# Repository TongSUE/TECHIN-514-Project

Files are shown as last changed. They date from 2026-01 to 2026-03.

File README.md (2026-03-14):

# TECHIN-514-Project : The Reality Color Dropper

## 1. Project Overview

**What it does:**
This project brings the digital "eyedropper" tool into real life. It consists of a pen-shaped device that scans the color of physical objects and a desktop station that displays the color data and the confidence level of the match. It helps designers capture colors from the real world instantly.

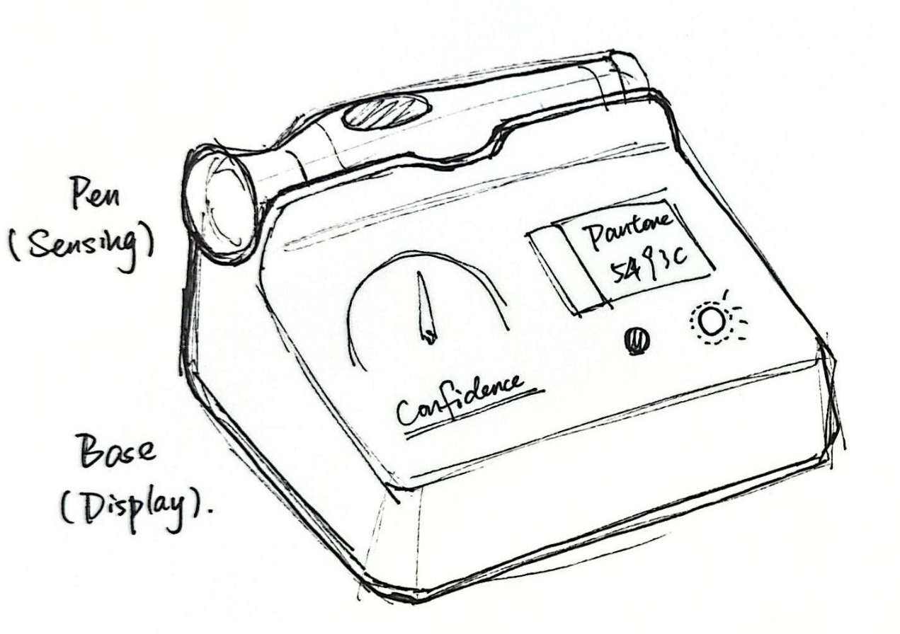
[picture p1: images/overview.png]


---

## 2. The Sensor Device (The Pen)

**Description:**
This is a handheld tool shaped like a marker pen. It utilizes a custom split-PCB architecture to fit the slim form factor. When the user finds a color, they press the button; the device reads the RGB value while blocking outside light and sends the data wirelessly to the base station.

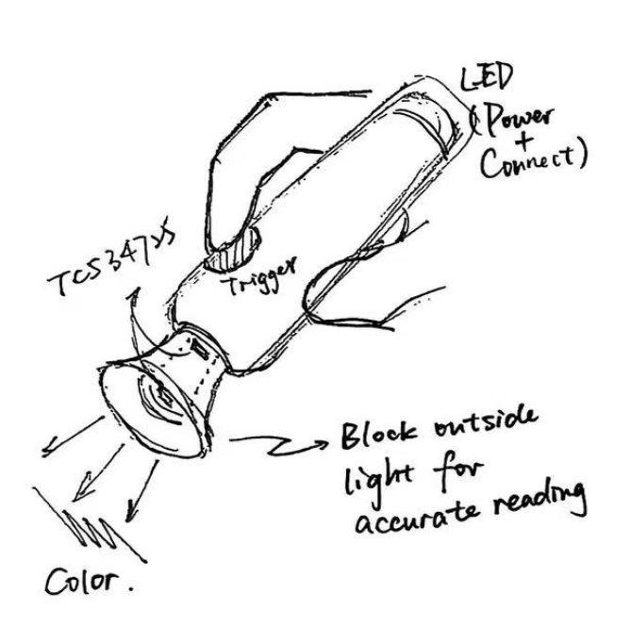
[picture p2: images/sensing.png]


**Key Components & Part Numbers:**

* **Controller: Seeed Studio XIAO ESP32C3**
    This thumb-sized microcontroller is selected for its compact footprint and built-in ESP-NOW capabilities. It fits perfectly inside the pen shaft.

* **Sensor Architecture: Split Custom PCB**
    To accommodate the pen's geometry, the circuit is split into two boards connected by a **1x4 Pin Header**:
    1.  **Main Board:** Vertically mounted inside the pen. Houses the MCU, battery pads, and switch.
    2.  **Sensor Tip:** A circular PCB mounted horizontally at the tip. Houses the **TCS34725 Sensor** and **LEDs** to ensure the sensor faces the paper perpendicularly.

* **Input: Tactile Button**
    Acts as a "shutter" trigger.

* **Power: Li-Po Battery (AAA size)**
    A cylindrical/prismatic lithium battery that connects to the motherboard via a battery holder.

* **Power Switch: Slide Switch**
    A side-mounted switch to cut off power completely.

---

## 3. The Display Device (The Base)

**Description:**
This is a desktop base that receives the color data. It features an OLED screen for data readout, a stepper motor gauge for visual feedback on accuracy, and a large LED for color reproduction.

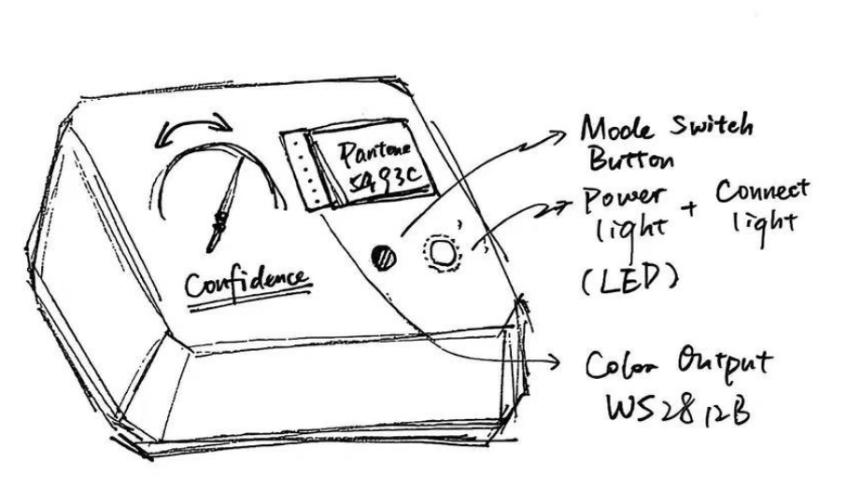
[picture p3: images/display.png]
Display device


**Key Components & Part Numbers:**

* **Controller: Seeed Studio XIAO ESP32C3**
    The base station uses the exact same controller as the pen. This unified architecture simplifies the codebase and BOM.

* **Display: 0.96" OLED Screen (SSD1306 Driver)**
    Displays the Hex/RGB codes via I2C interface.

* **Color Output: RGB LED**
    A programmable NeoPixel LED to visually visually recreate the scanned color.

* **Motor: x27_168 Stepper Motor**
    Indicates the "Confidence Level" (Euclidean distance) of the color match.

* **Power: 18650 Li-Ion Battery**
    Provides long-lasting power, boosted to 5V for the motor and LEDs.

---

## 4. System Logic & Communication

**Communication Method:**
The devices talk to each other using **ESP-NOW**.
* It is a peer-to-peer protocol (low latency).
* It does not require a router or Wi-Fi pairing.

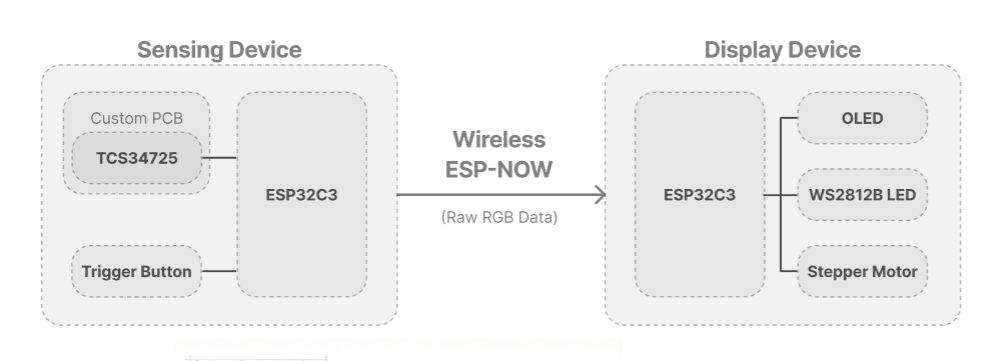
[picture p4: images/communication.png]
Communication


**Workflow:**

1.  **Trigger:** User clicks the pen button.
2.  **Sensing:** The TCS34725 sensor (on the Daughterboard) reads the Raw RGB data.
3.  **Sending:** The Pen (XIAO ESP32C3) processes the data and sends it via ESP-NOW.
4.  **Receiving:** The Base (XIAO ESP32C3) receives the packet.
5.  **Processing (DSP/ML):** The Base calculates the **Euclidean Distance** between the scanned color and a stored color library (KNN algorithm).
6.  **Output:**
    * The **OLED** shows the color code.
    * The **Neopixel LED** lights up in that color.
    * The **Stepper Motor** moves the needle to show the confidence level.

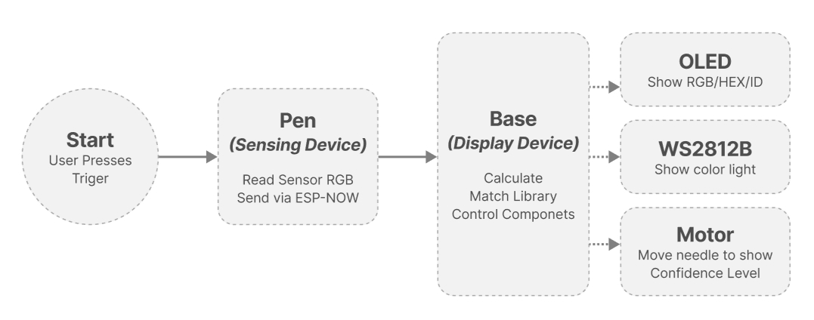
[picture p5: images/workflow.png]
Workflow


---

# Electrical Schematics & PCB Layout

## Custom PCB Design
The pen utilizes a custom **Split-PCB Design** to manage the directional requirements of the sensor.

The split-PCB architecture is implemented to allow the sensor to sit perpendicular to the scanning surface for accurate readings, while the main controller fits vertically within the narrow pen shaft.

* **Connection:** The Main Board and Sensor Tip are linked via a flexible **1x5 Connector** carrying 3.3V, GND, SDA, SCL, and LED Control.
* **Power:** The battery connects to the tail of the Main Board via a **1x2 Connector**.

### **Custom PCB Screenshots**
- Sensing - Sensor Tip
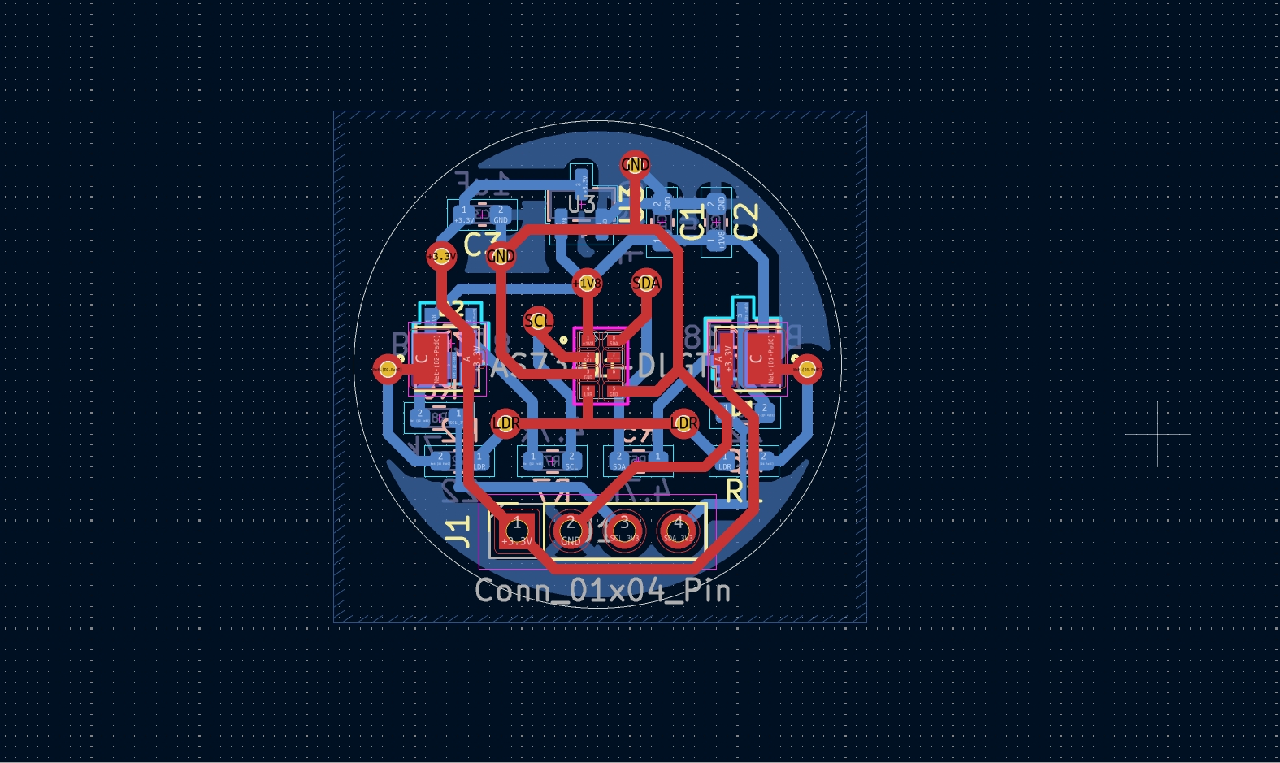
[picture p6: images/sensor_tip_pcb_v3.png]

- Sensing - Main Board
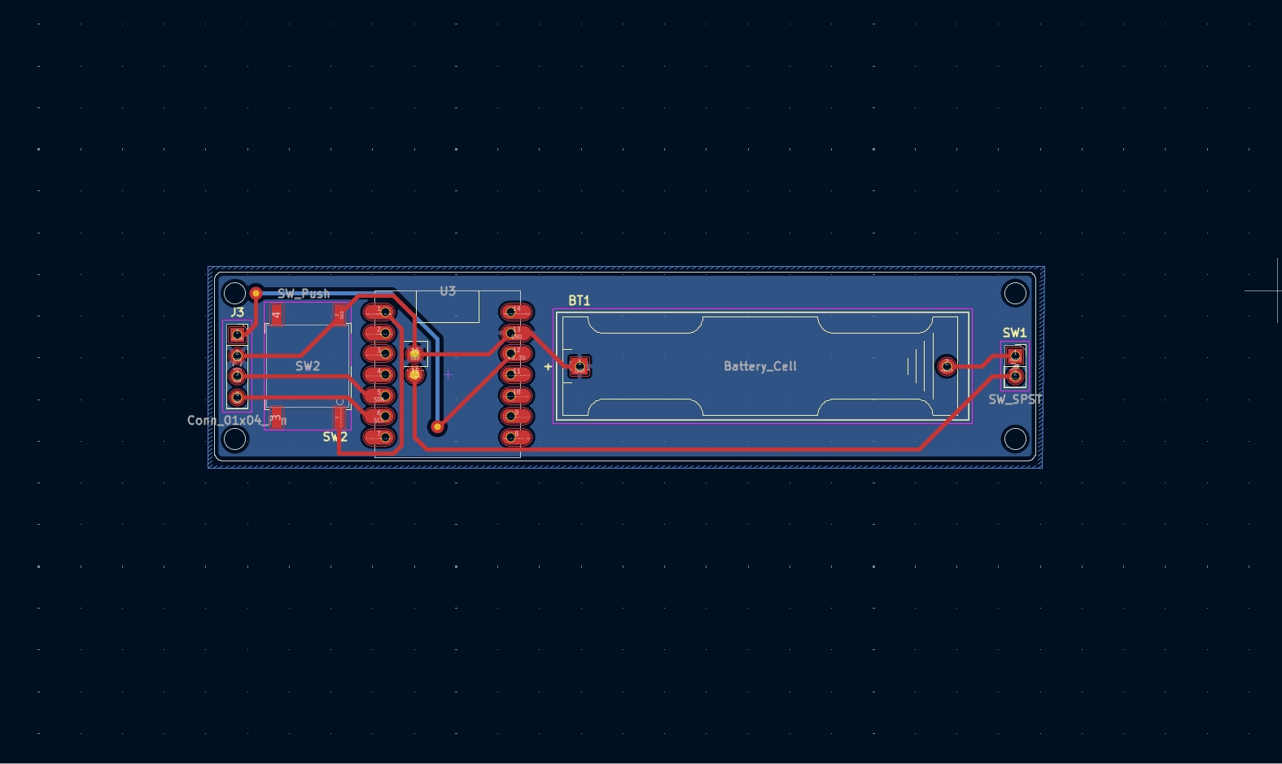
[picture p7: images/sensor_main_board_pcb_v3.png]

- Display
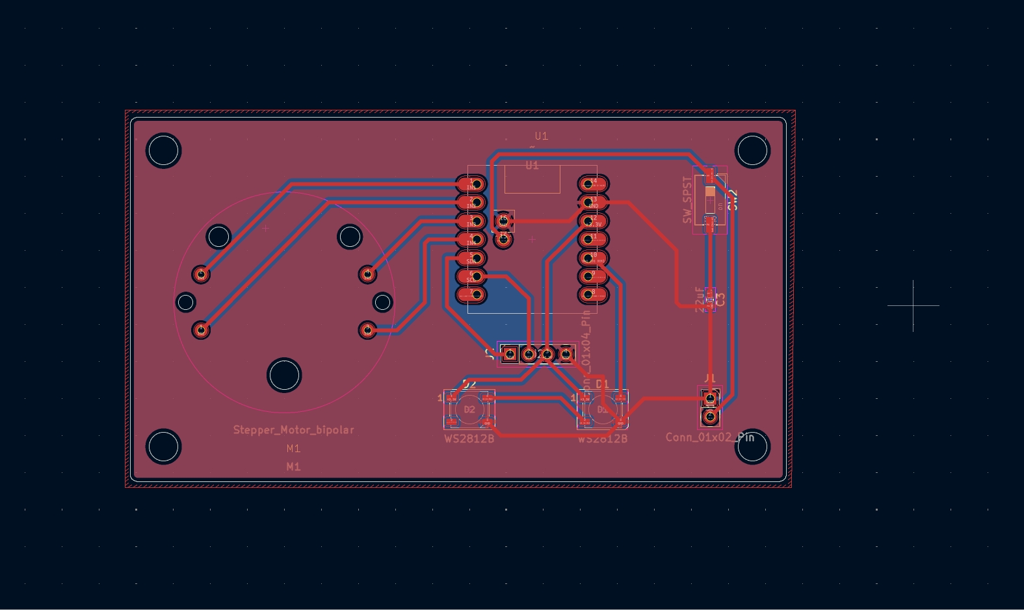
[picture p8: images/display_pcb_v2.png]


## Circuit Schematics

### **Sensing Device Schematic**
- Sensor Tip
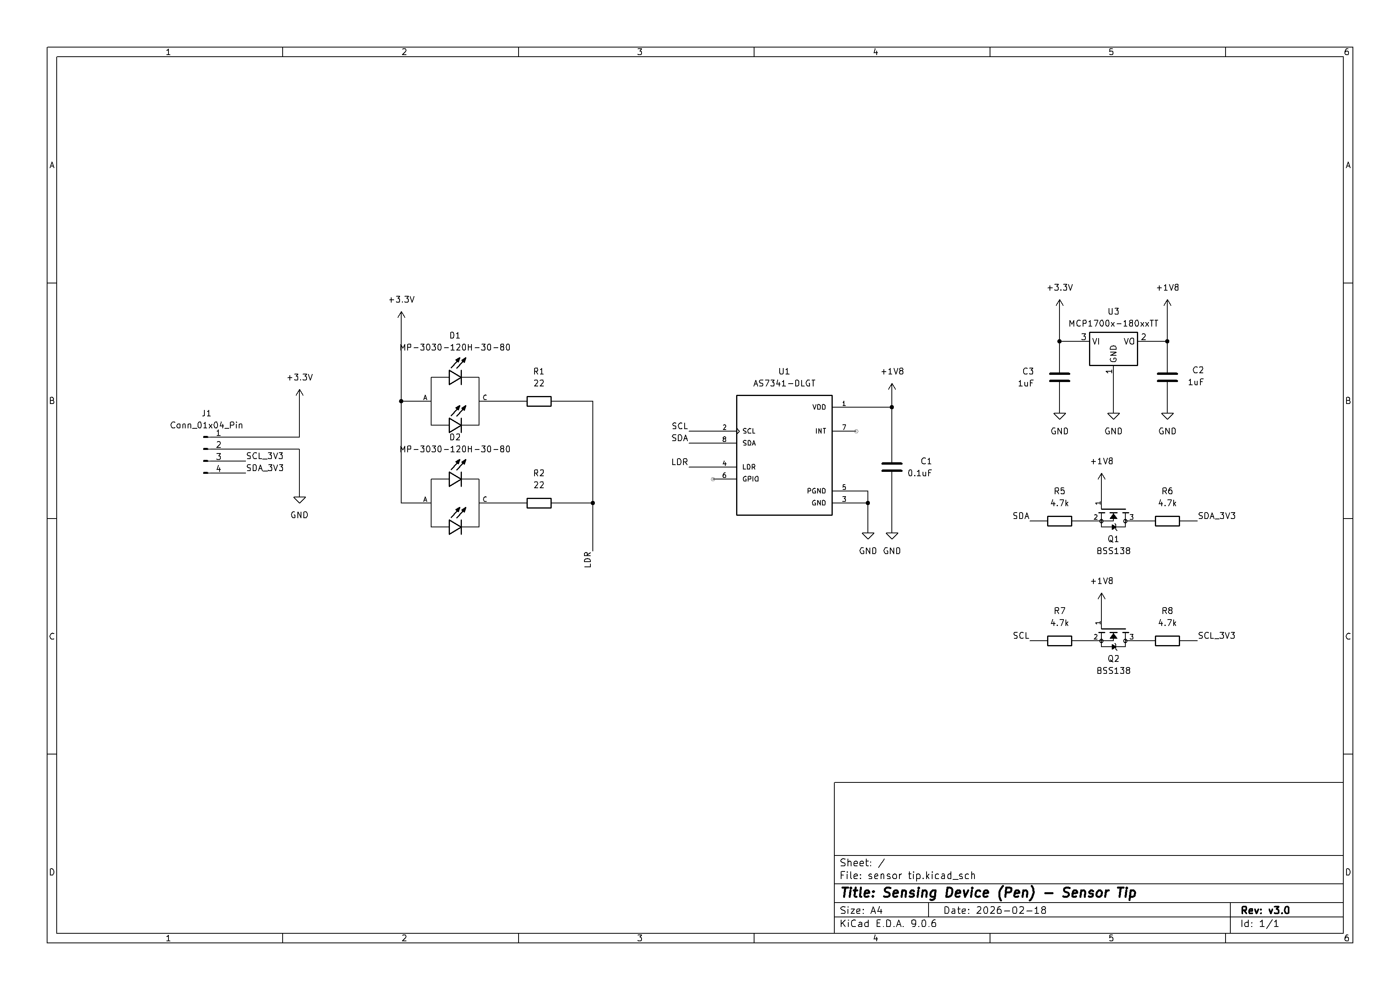
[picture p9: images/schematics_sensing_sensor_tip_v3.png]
Electrical schematics of Sensing device


- Main Board
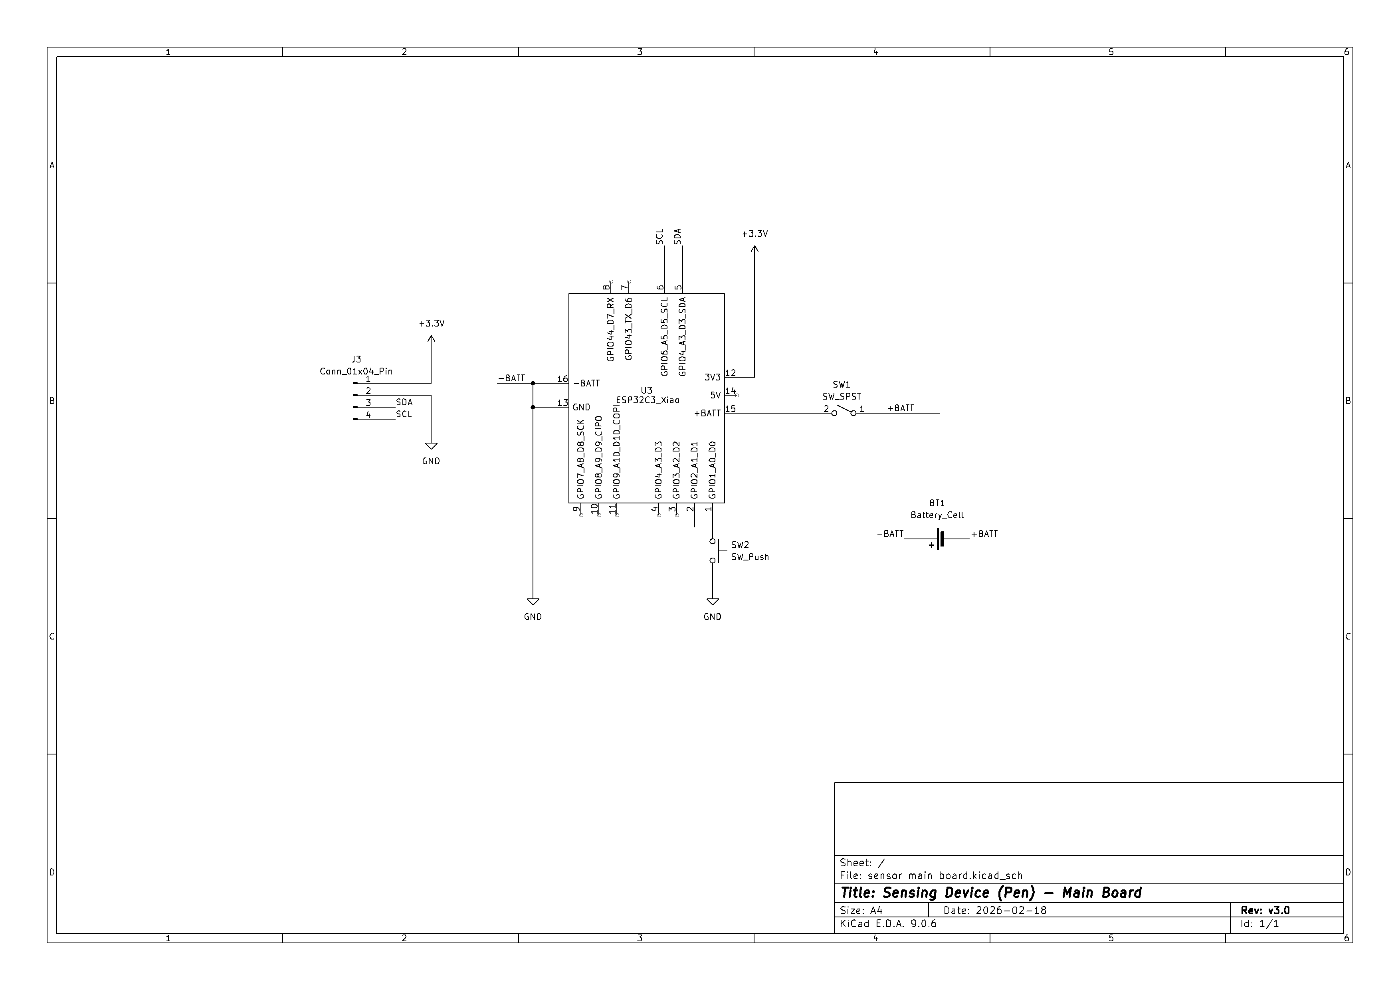
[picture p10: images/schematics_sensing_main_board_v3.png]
Electrical schematics of Sensing device


### **Display Device Schematic**

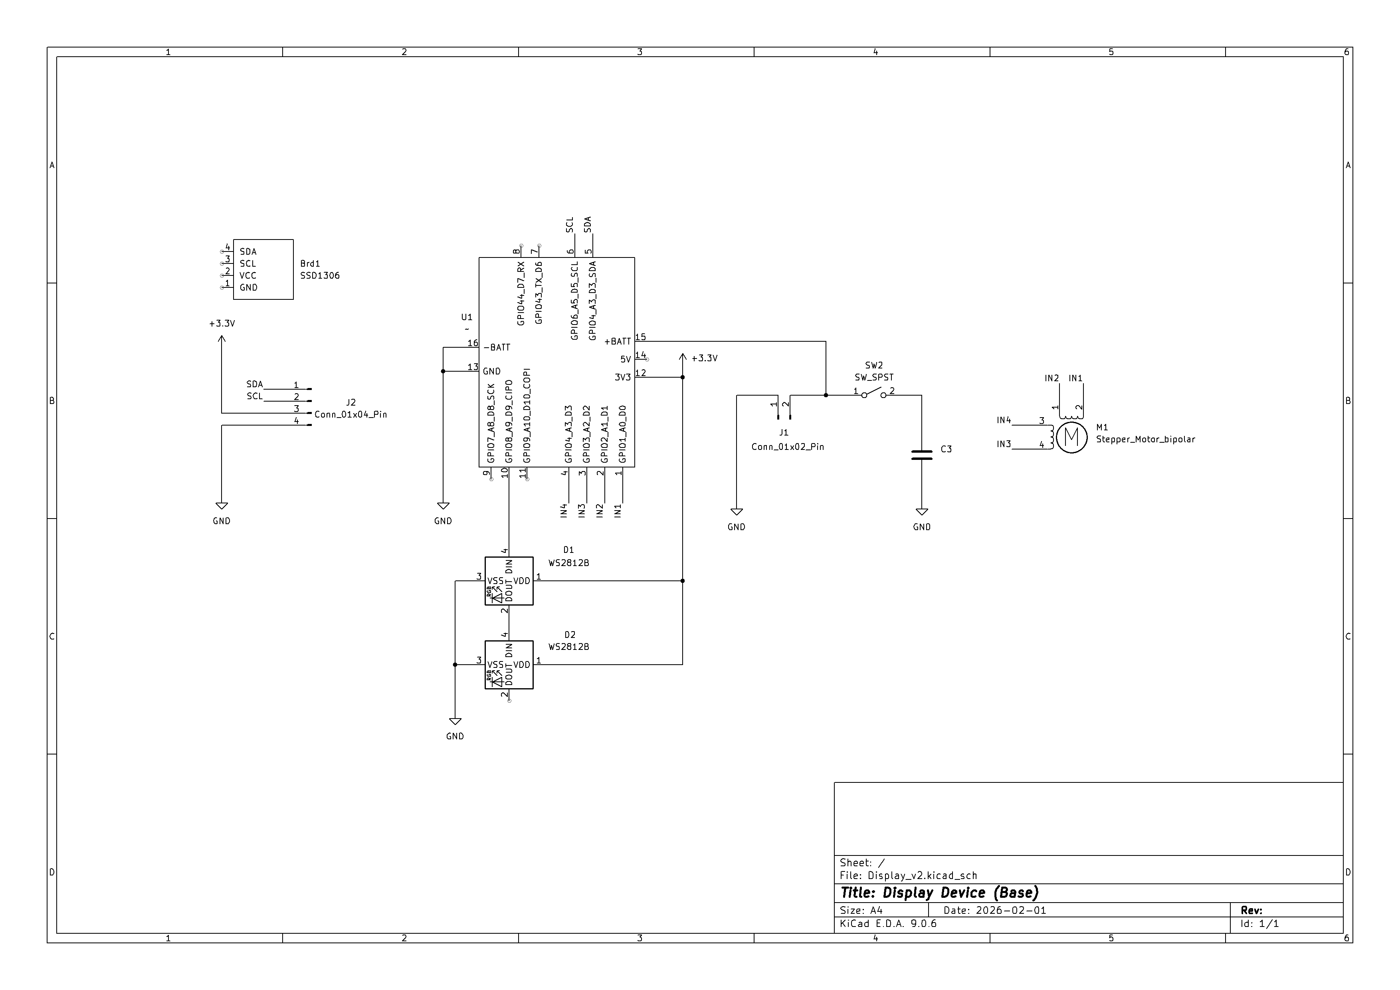
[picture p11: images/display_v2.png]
Electrical schematics of Display device


---

# BOM

- [Sensing - Sensor Tip BOM](./schematics/Sensing_v3/sensor%20tip/sensor%20tip.csv)
- [Sensing - Main Board BOM](./schematics/Sensing_v2/sensor%20main%20board.csv)
- [Display BOM](./schematics/Display_v2/Display_v2.csv)

---

# Battery Estimate
- [Simple Power Model (Google Doc)](https://docs.google.com/spreadsheets/d/19ngwSyrM9dyAIHHAB65ps8SqUUKRAjS5MIs19pbbb7s/edit?usp=sharing)

---

# Enclosure Design
- [Enclosure Design](./enclosure/)

### Sensing Device
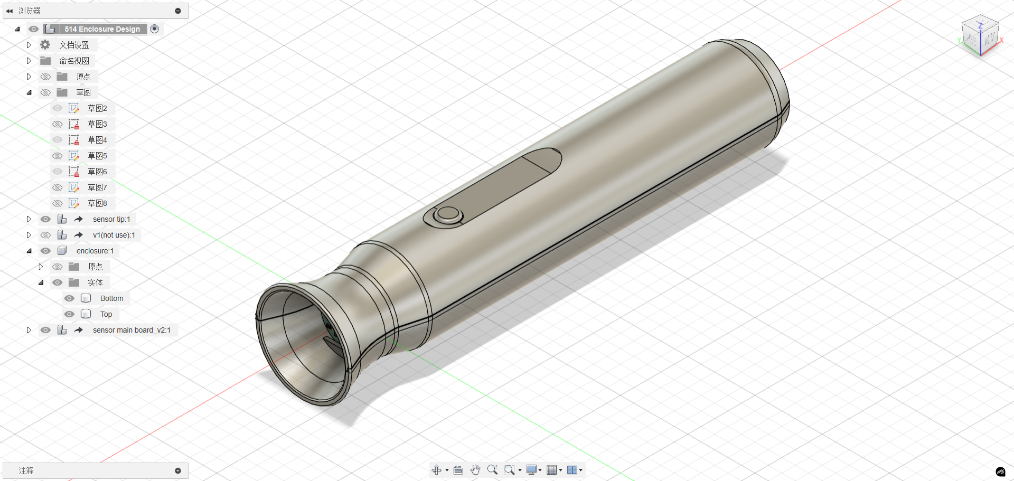
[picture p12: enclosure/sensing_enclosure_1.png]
Enclosure Design of Sensing device


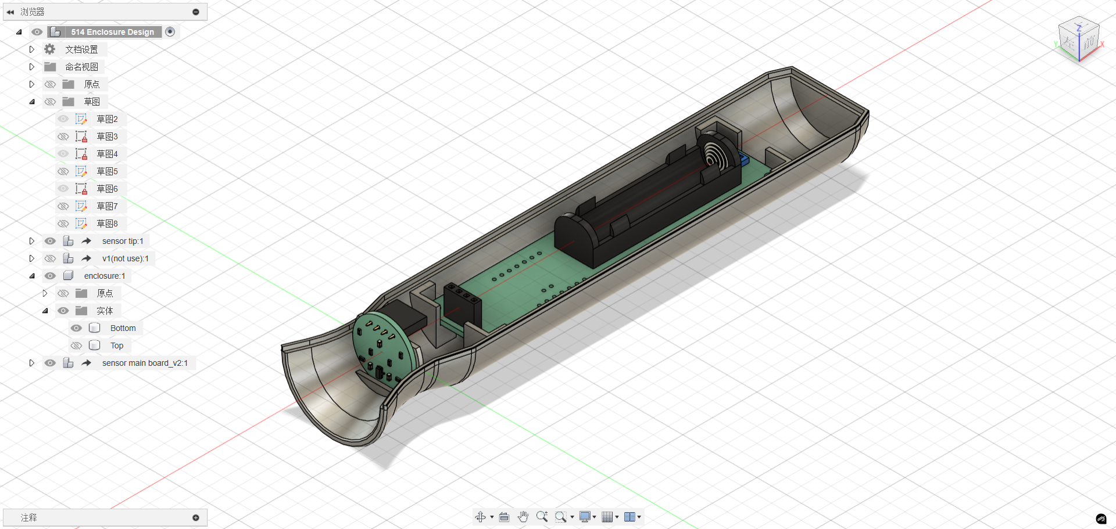
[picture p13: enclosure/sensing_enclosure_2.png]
Enclosure Design of Sensing device


### Display Device
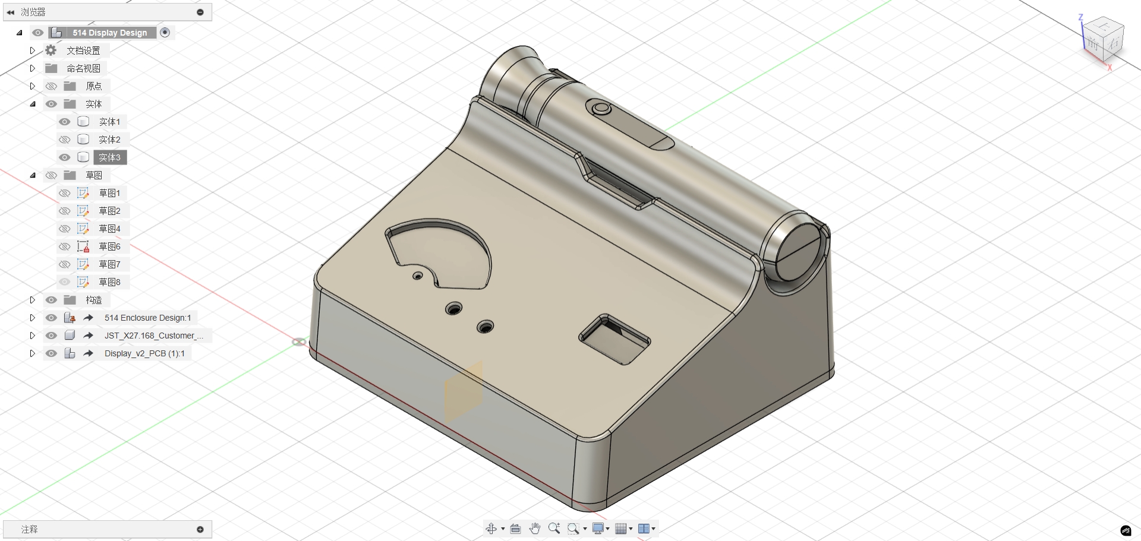
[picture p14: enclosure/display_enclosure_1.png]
Enclosure Design of Sensing device


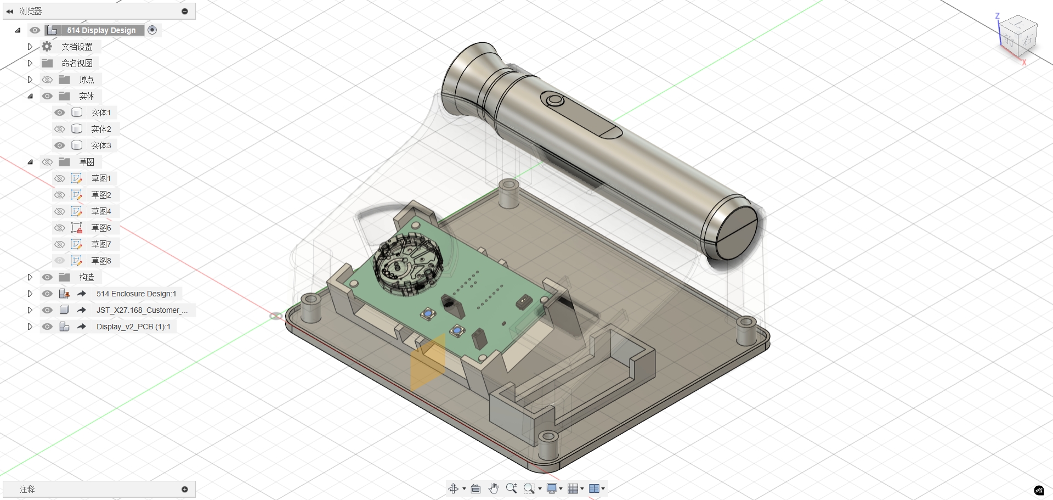
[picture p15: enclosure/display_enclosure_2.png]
Enclosure Design of Sensing device


---

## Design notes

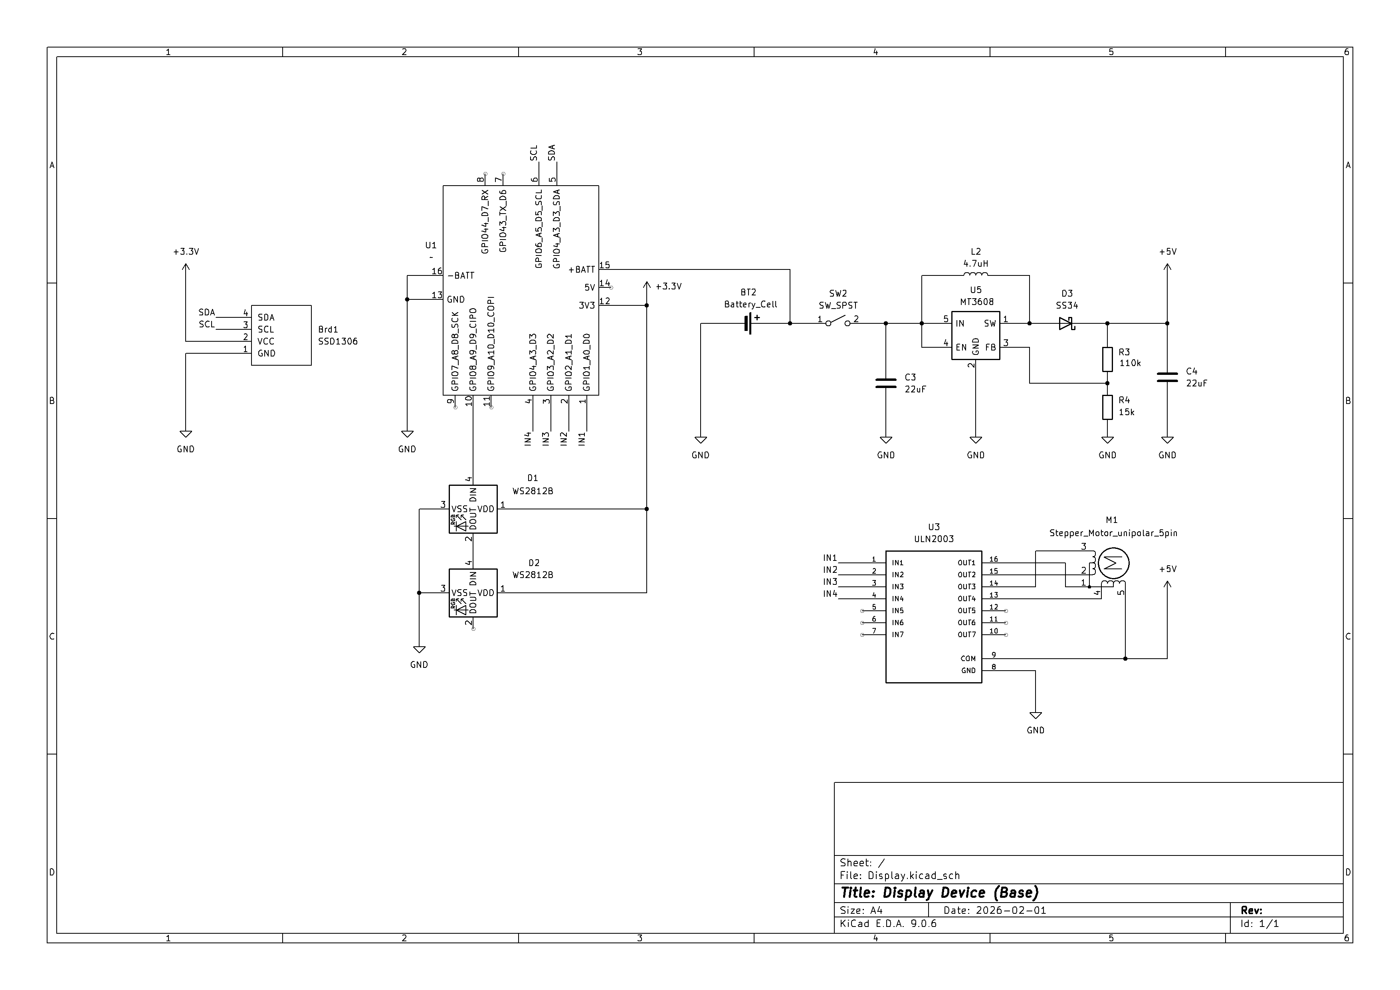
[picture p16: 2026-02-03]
images/schematics_display.png

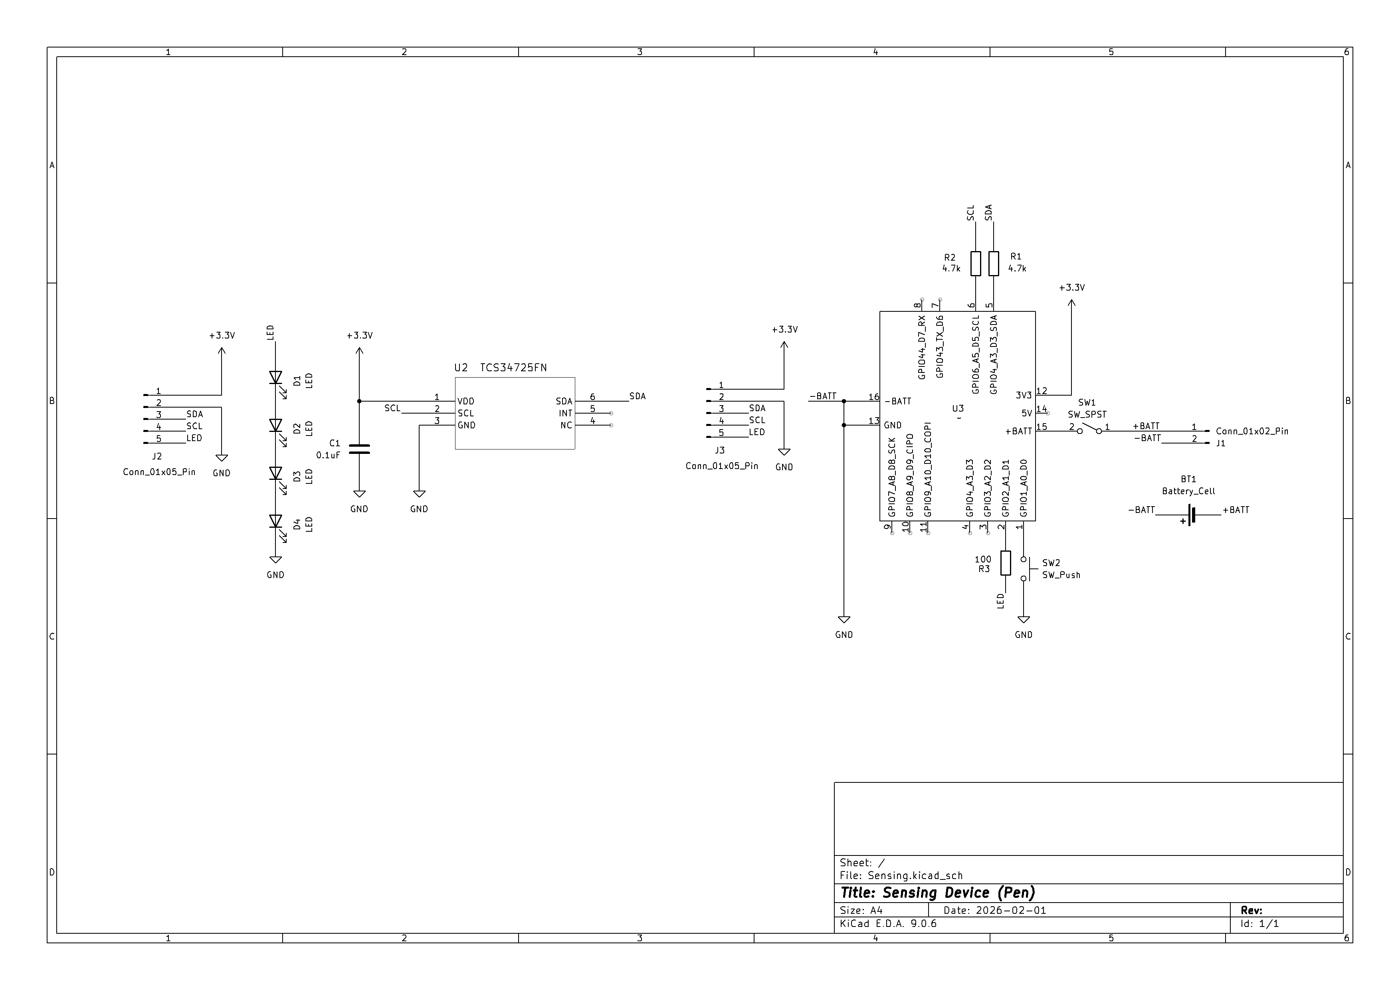
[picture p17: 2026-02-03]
images/schematics_sensing.png

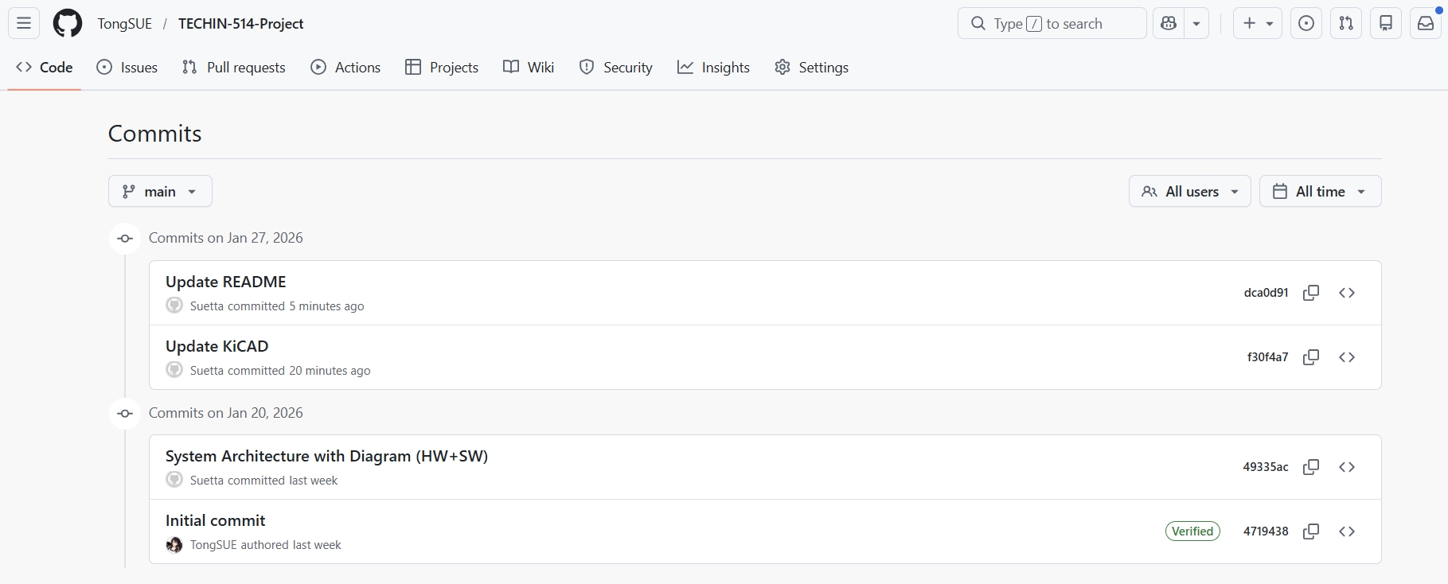
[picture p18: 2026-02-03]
schematics/Screenshots.png

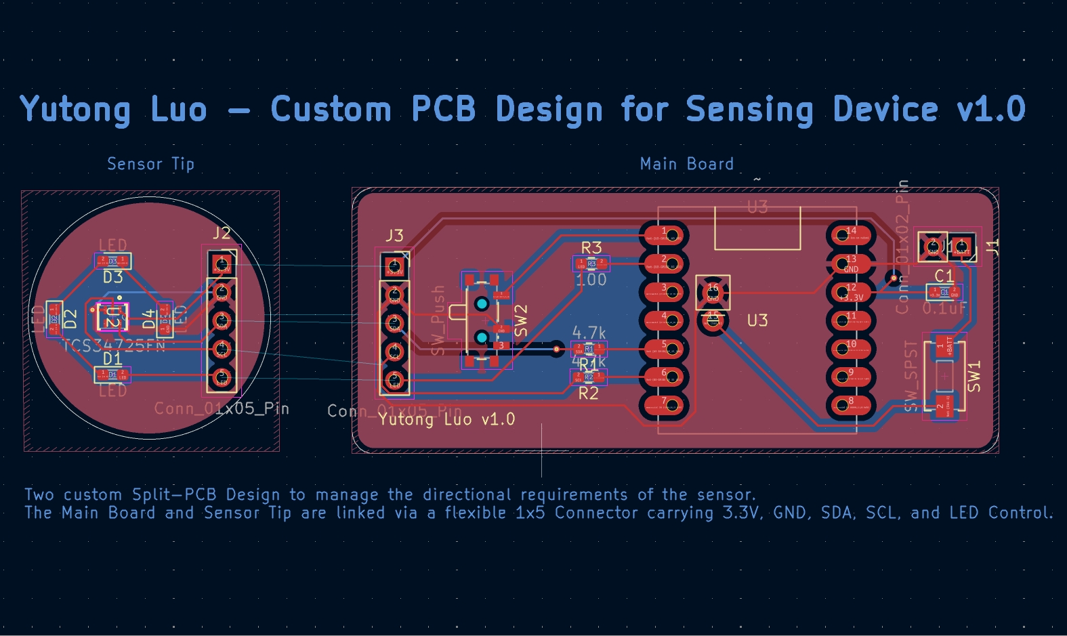
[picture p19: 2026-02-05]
custom PCB/PCB design screenshots.png

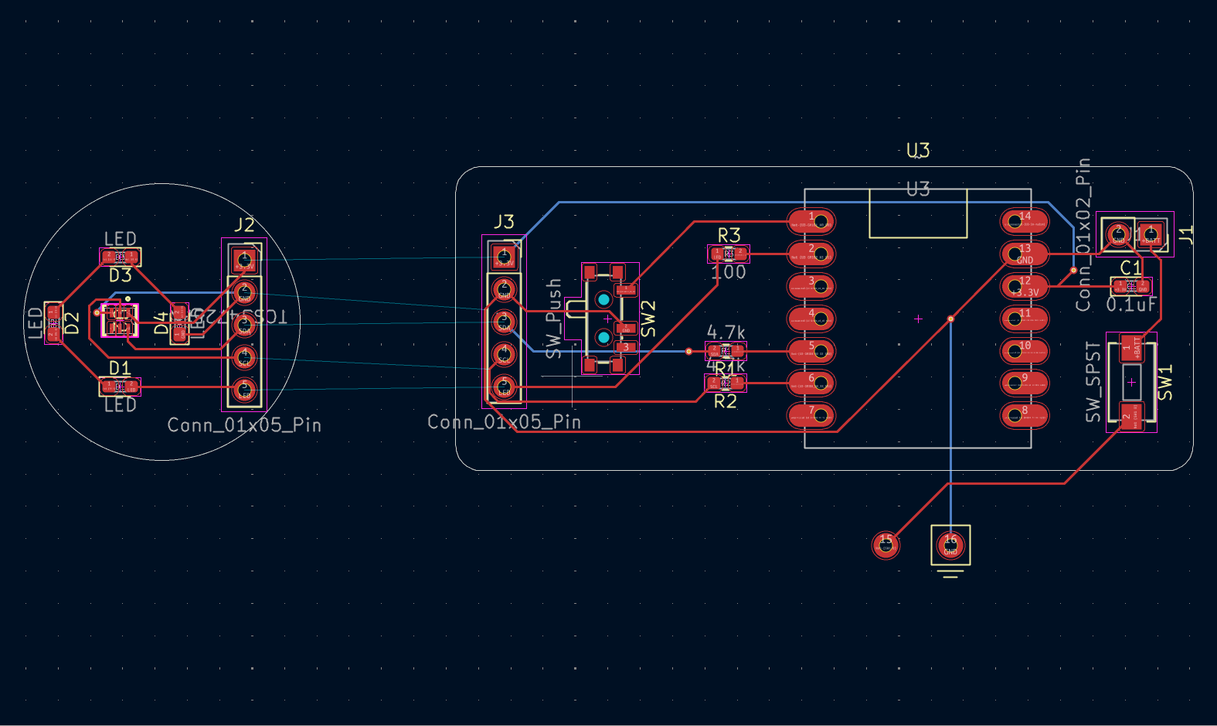
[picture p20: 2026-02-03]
images/custom_PCB.png

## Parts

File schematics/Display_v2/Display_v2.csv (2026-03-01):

Reference | Qty | Value | DNP | Exclude from BOM | Exclude from Board | Footprint | Datasheet
Brd1 | 1 | SSD1306 |  |  |  | Display:Adafruit_SSD1306_No_Mounting_Holes
C3 | 1 | 22uF |  |  |  | Capacitor_SMD:C_0603_1608Metric_Pad1.08x0.95mm_HandSolder | ~
D1,D2 | 2 | WS2812B |  |  |  | LED_SMD:LED_WS2812B_PLCC4_5.0x5.0mm_P3.2mm | https://cdn-shop.adafruit.com/datasheets/WS2812B.pdf
J1 | 1 | Conn_01x02_Pin |  |  |  | Connector_PinSocket_2.54mm:PinSocket_1x02_P2.54mm_Vertical | ~
J2 | 1 | Conn_01x04_Pin |  |  |  | Connector_PinSocket_2.54mm:PinSocket_1x04_P2.54mm_Vertical | ~
M1 | 1 | Stepper_Motor_bipolar |  |  |  | x27_168:x27_stepper_two_holes | http://www.infineon.com/dgdl/Application-Note-TLE8110EE_driving_UniPolarStepperMotor_V1.1.pdf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
SW2 | 1 | SW_SPST |  |  |  | Button_Switch_SMD:SW_DIP_SPSTx01_Slide_6.7x4.1mm_W6.73mm_P2.54mm_LowProfile_JPin | ~
U1 | 1 | ~ |  |  |  | ESP32_Xiao_Seeed_GIX:XIAO_ESP32

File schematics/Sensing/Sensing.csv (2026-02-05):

Reference | Qty | Value | DNP | Exclude from BOM | Exclude from Board | Footprint | Datasheet
BT1 | 1 | Battery_Cell |  |  |  | Xiao_Seeed_ESP32C3:MOUDLE14P-SMD-2.54-21X17.8MM | ~
C1 | 1 | 0.1uF |  |  |  | Capacitor_SMD:C_0603_1608Metric_Pad1.08x0.95mm_HandSolder | ~
D1,D2,D3,D4 | 4 | LED |  |  |  | LED_SMD:LED_0603_1608Metric_Pad1.05x0.95mm_HandSolder | ~
J1 | 1 | Conn_01x02_Pin |  |  |  | Connector_PinSocket_2.54mm:PinSocket_1x02_P2.54mm_Vertical | ~
J2,J3 | 2 | Conn_01x05_Pin |  |  |  | Connector_PinSocket_2.54mm:PinSocket_1x05_P2.54mm_Vertical | ~
R1,R2 | 2 | 4.7k |  |  |  | Resistor_SMD:R_0603_1608Metric_Pad0.98x0.95mm_HandSolder | ~
R3 | 1 | 100 |  |  |  | Resistor_SMD:R_0603_1608Metric_Pad0.98x0.95mm_HandSolder | ~
SW1 | 1 | SW_SPST |  |  |  | Button_Switch_SMD:SW_SPST_EVQPE1 | ~
SW2 | 1 | SW_Push |  |  |  | Button_Switch_SMD:SW_SPDT_PCM12 | ~
U2 | 1 | TCS34725FN |  |  |  | TCS34725:TCS34725FN_AMS | TCS34725FN
U3 | 1 | ESP32C3_Xiao |  |  |  | ESP32_Xiao_Seeed_GIX:XIAO_ESP32

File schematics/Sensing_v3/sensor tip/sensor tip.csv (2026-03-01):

Reference | Qty | Value | DNP | Exclude from BOM | Exclude from Board | Footprint | Datasheet
C1 | 1 | 0.1uF |  |  |  | Capacitor_SMD:C_0603_1608Metric_Pad1.08x0.95mm_HandSolder | ~
C2,C3 | 2 | 1uF |  |  |  | Capacitor_SMD:C_0603_1608Metric_Pad1.08x0.95mm_HandSolder | ~
D1,D2 | 2 | MP-3030-120H-30-80 |  |  |  | MP_3030_120H_30_80:LED_MP-3030-120H-30-80
J1 | 1 | Conn_01x04_Pin |  |  |  | Connector_PinSocket_2.54mm:PinSocket_1x04_P2.54mm_Vertical | ~
Q1,Q2 | 2 | BSS138 |  |  |  | BSS138:SOT-23_3L_ONS
R1,R2 | 2 | 22 |  |  |  | Resistor_SMD:R_0603_1608Metric_Pad0.98x0.95mm_HandSolder | ~
R5,R6,R7,R8 | 4 | 4.7k |  |  |  | Resistor_SMD:R_0603_1608Metric_Pad0.98x0.95mm_HandSolder | ~
U1 | 1 | AS7341-DLGT |  |  |  | AS7341_DLGT:SON8_AS7341-DLGM_AMS
U3 | 1 | MCP1700x-180xxTT |  |  |  | Package_TO_SOT_SMD:SOT-23 | http://ww1.microchip.com/downloads/en/DeviceDoc/20001826D.pdf

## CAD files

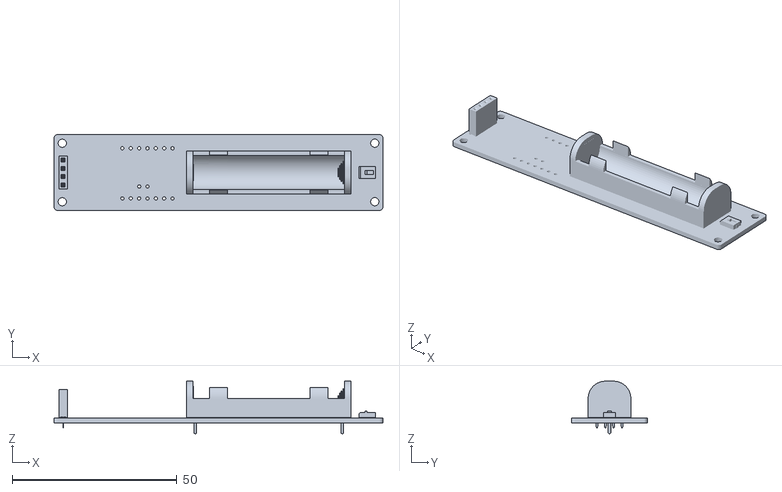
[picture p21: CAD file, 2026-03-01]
enclosure/sensor main board_v2.stl
100.0 x 23.0 x 16.0

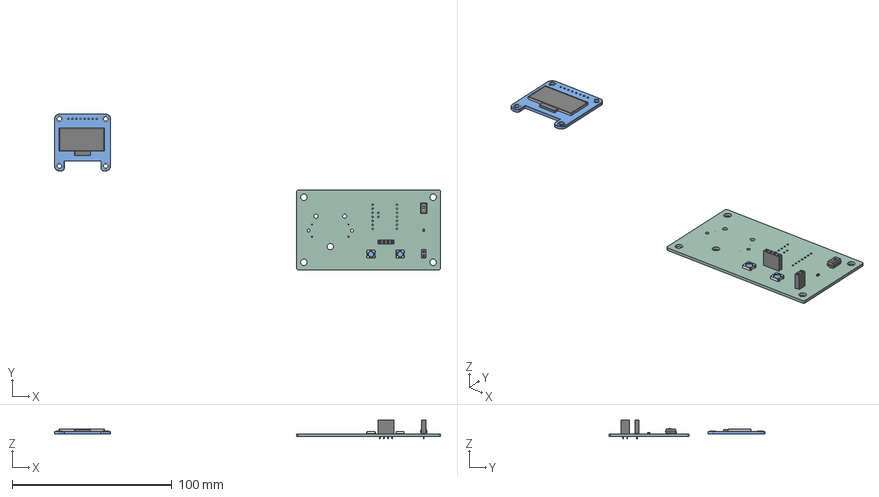
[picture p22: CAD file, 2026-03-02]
enclosure/Display_v2_PCB.step
241.3 x 97.5 x 11.6 mm
LED_WS2812B_PLCC4_5.0x5.0mm_P3.2mm x 2
C_0603_1608Metric
SW_DIP_SPSTx01_Slide_6.7x4.1mm_W6.73mm_P2.54mm_LowProfile_JPin
Adafruit_SSD1306
PinSocket_1x04_P2.54mm_Vertical
PinSocket_1x02_P2.54mm_Vertical
Display_v2_PCB

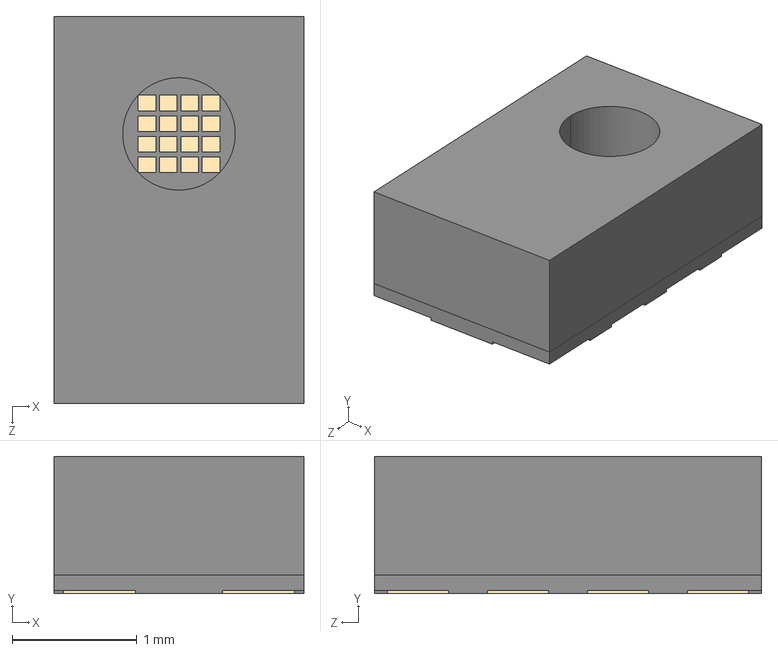
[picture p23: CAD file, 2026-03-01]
KiCAD Models/AS7341_DLGT/AS7341-DLGT.step
2.00 x 1.10 x 3.10 mm

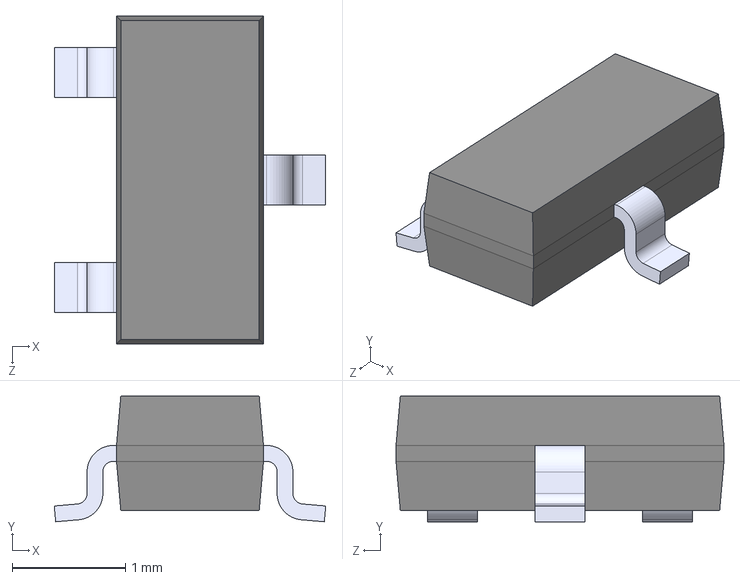
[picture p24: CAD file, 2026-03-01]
KiCAD Models/BSS138/BSS138.step
2.40 x 1.11 x 2.90 mm

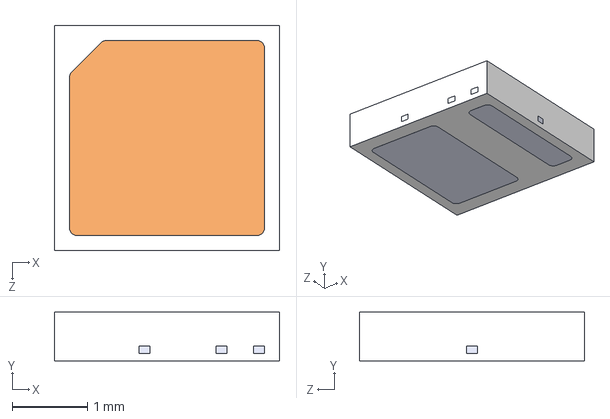
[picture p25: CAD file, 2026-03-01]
KiCAD Models/MP_3030_120H_30_80/MP-3030-120H-30-80.step
3.00 x 0.65 x 3.00 mm

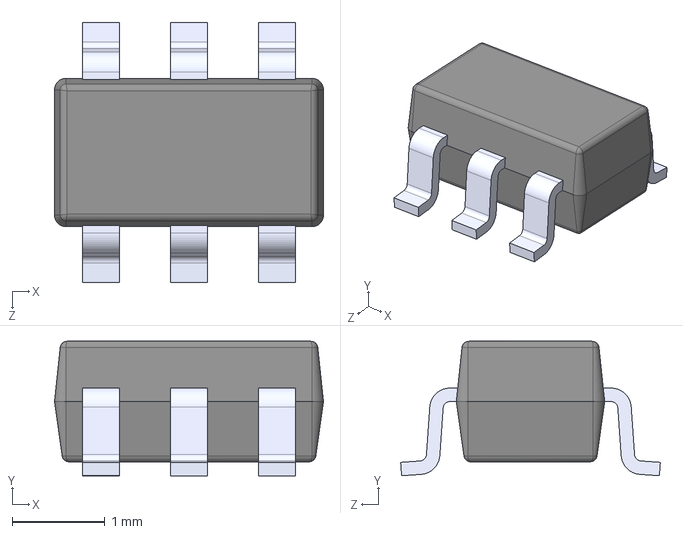
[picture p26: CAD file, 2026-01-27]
KiCAD Models/MT3608/MT3608.step
2.90 x 1.45 x 2.80 mm

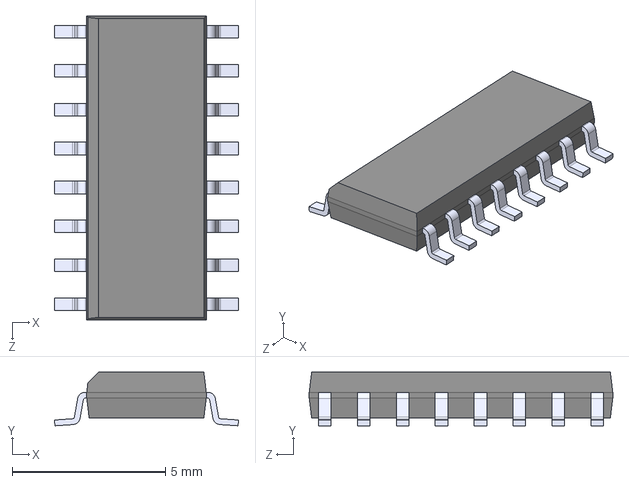
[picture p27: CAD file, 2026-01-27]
KiCAD Models/ULN2003/ULN2003.step
6.00 x 1.75 x 9.90 mm

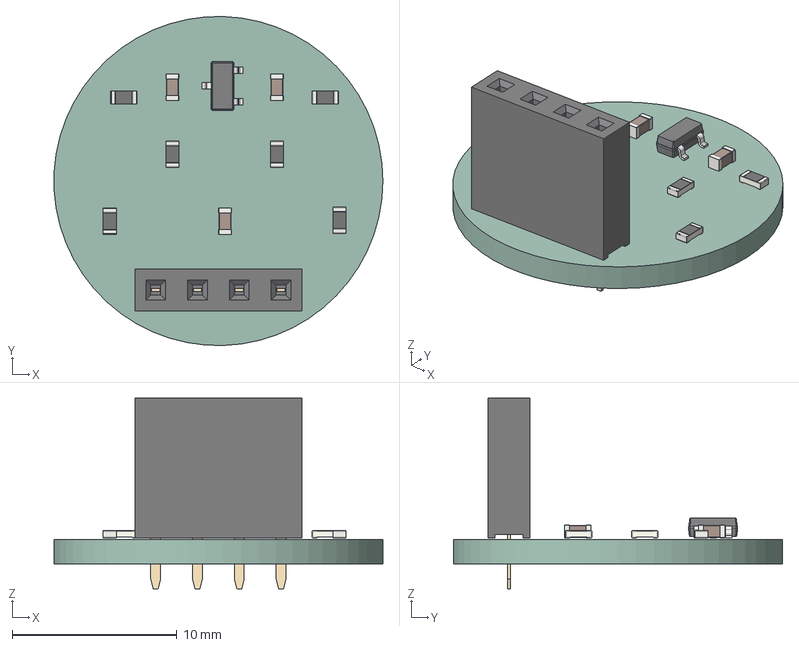
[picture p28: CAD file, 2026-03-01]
schematics/Sensing/Sensing.step
20.0 x 20.0 x 11.6 mm
R_0603_1608Metric x 6
SOT-23
C_0603_1608Metric x 3
PinSocket_1x04_P2.54mm_Vertical
Sensing_PCB

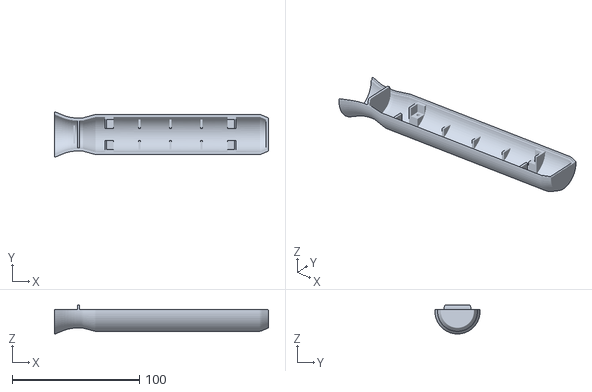
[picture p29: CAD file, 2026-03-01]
enclosure/Bottom.stl
168.2 x 35.5 x 22.7

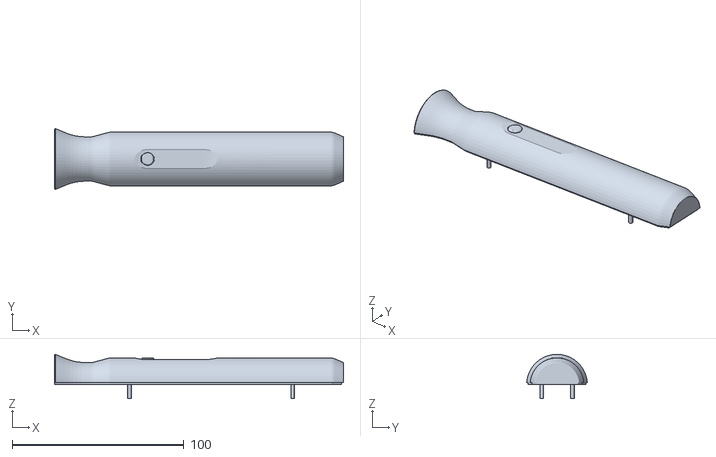
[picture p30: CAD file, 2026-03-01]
enclosure/Top.stl
168.2 x 35.4 x 25.7

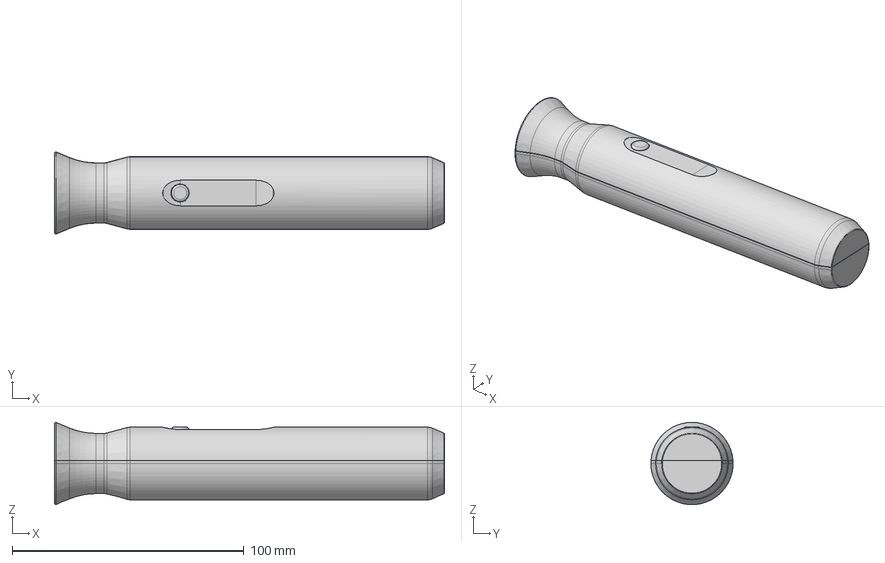
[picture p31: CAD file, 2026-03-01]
enclosure/514 Enclosure Design.step
168.2 x 35.5 x 35.5 mm
R_0603_1608Metric x 6
SOT-23
C_0603_1608Metric x 3
PinSocket_1x04_P2.54mm_Vertical
Sensing_PCB
PinSocket_1x04_P2.54mm_Vertical_1
SW_SPST_EVQPE002
SW_SPST_EVQPE1_1
BatteryHolder_Keystone_2466_1xAAA
sensor main board_PCB

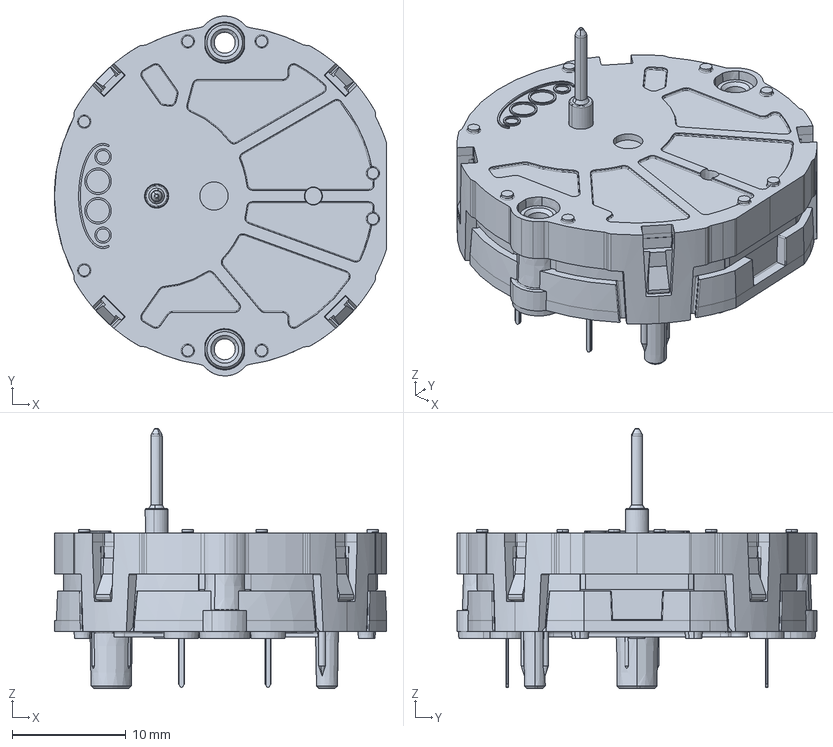
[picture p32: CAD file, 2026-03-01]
enclosure/JST_X27.168_Customer_3D.stp
29.3 x 31.7 x 22.9 mm

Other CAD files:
enclosure/sensor tip.stl
schematics/Sensing_v2/sensor main board.step
enclosure/514 Enclosure Design.f3z

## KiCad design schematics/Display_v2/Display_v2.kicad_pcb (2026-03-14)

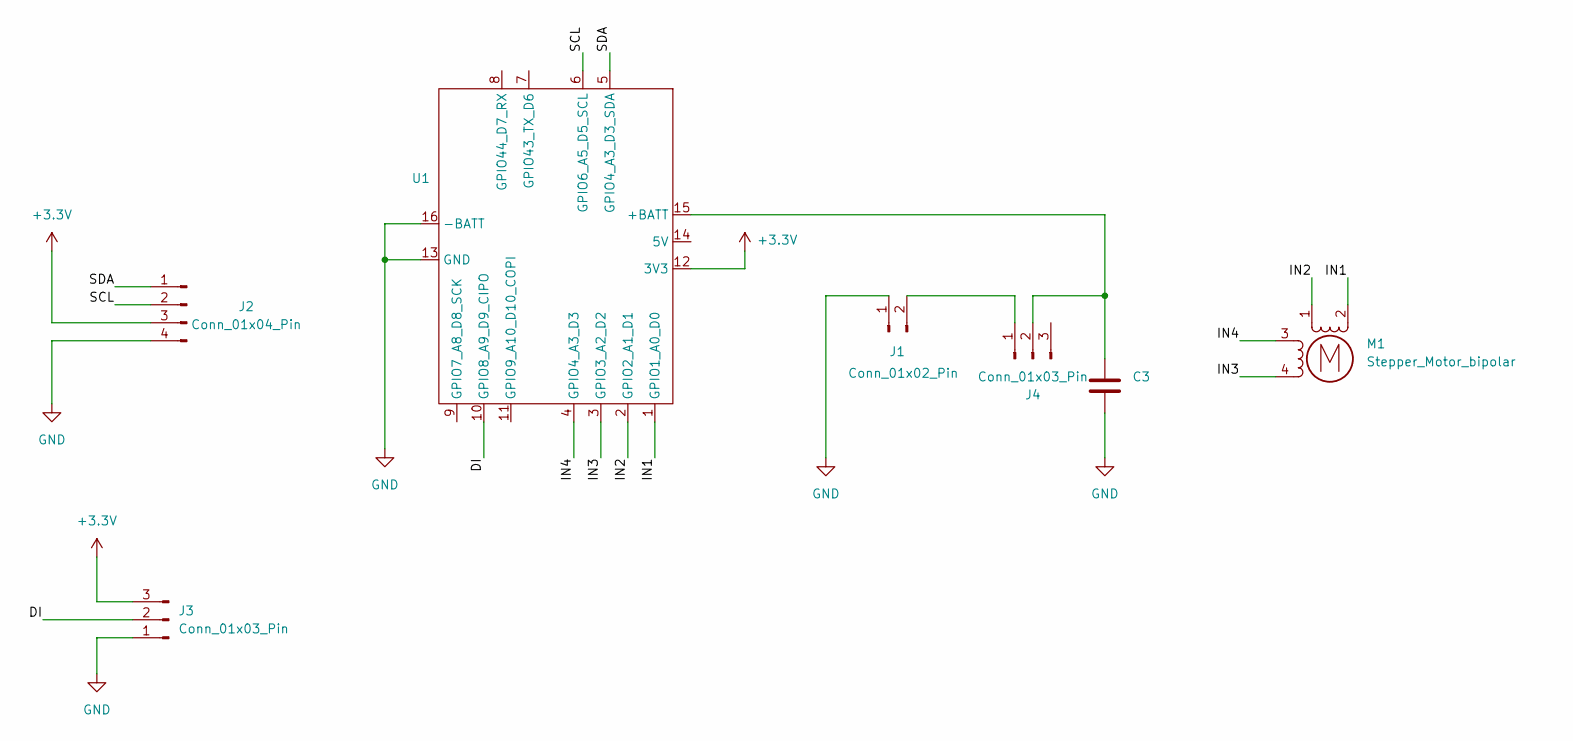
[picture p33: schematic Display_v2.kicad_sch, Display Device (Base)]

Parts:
C3: 22uF; C_0603_1608Metric_Pad1.08x0.95mm_HandSolder
J1: Conn_01x02_Pin; PinSocket_1x02_P2.54mm_Vertical
J2: Conn_01x04_Pin; PinSocket_1x04_P2.54mm_Vertical
J3, J4: Conn_01x03_Pin; PinSocket_1x03_P2.54mm_Vertical
M1: Stepper_Motor_bipolar; x27_stepper_two_holes
U1: XIAO_ESP32

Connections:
+3.3V: J2.3, J3.3, U1.12 (3V3)
/DI: J3.2, U1.10 (GPIO8_A9_D9_CIPO)
/IN1: M1.2 (-), U1.1 (GPIO1_A0_D0)
/IN2: M1.1, U1.2 (GPIO2_A1_D1)
/IN3: M1.4, U1.3 (GPIO3_A2_D2)
/IN4: M1.3, U1.4 (GPIO4_A3_D3)
/SCL: J2.2, U1.6 (GPIO6_A5_D5_SCL)
/SDA: J2.1, U1.5 (GPIO4_A3_D3_SDA)
GND: C3.2, J1.1, J2.4, J3.1, U1.13 (GND), U1.16 (-BATT)
unnamed: J1.2, J4.1
unnamed: C3.1, J4.2, U1.15 (+BATT)

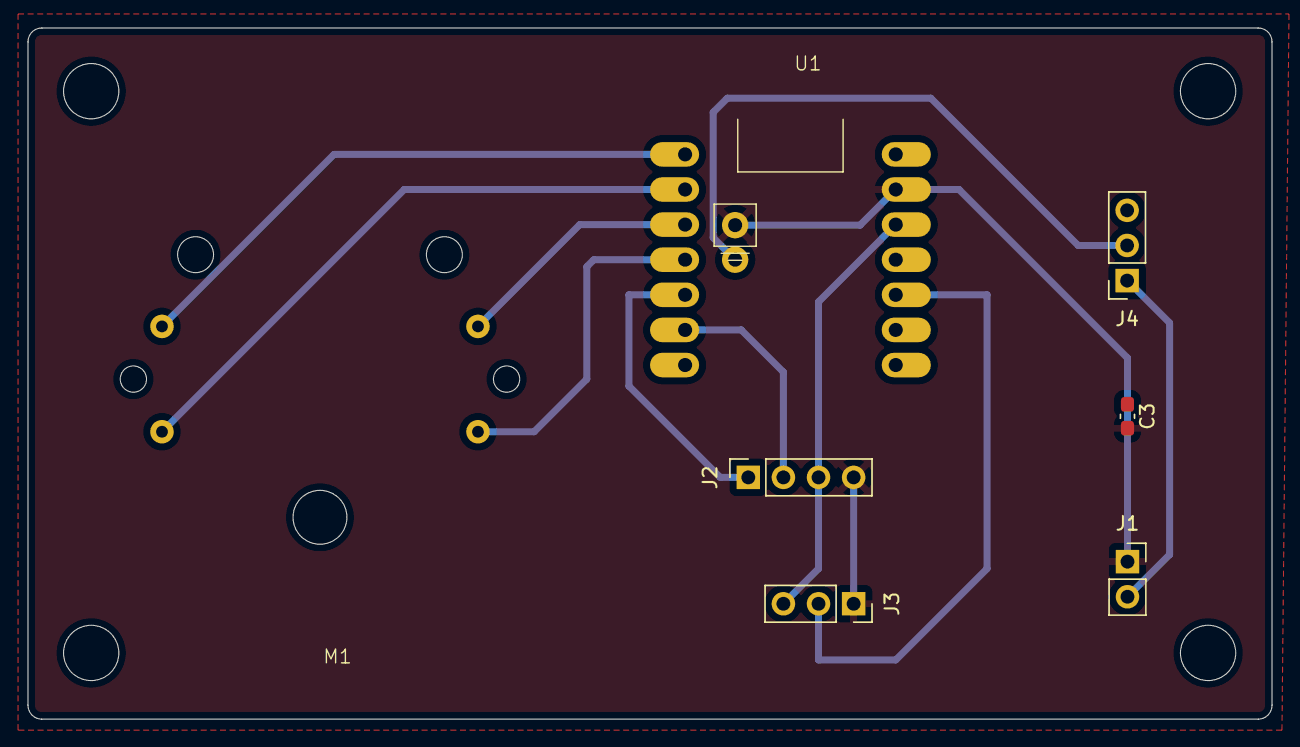
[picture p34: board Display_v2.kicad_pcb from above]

Board: 2 copper layers, 90.0 x 50.0 mm, 7 parts (0 on the bottom side), 11 nets.

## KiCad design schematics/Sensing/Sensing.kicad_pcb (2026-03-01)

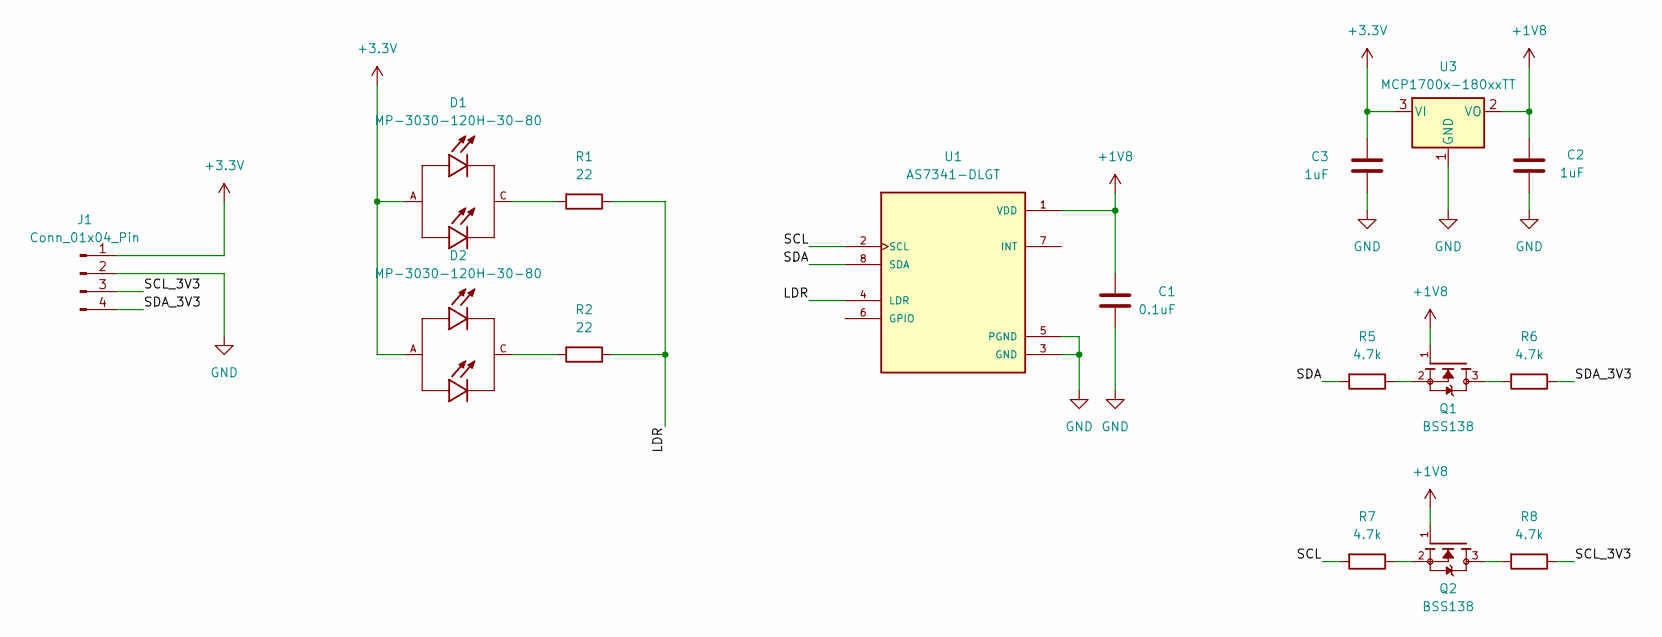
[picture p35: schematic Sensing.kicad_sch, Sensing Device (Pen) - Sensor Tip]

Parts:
C1: 0.1uF; C_0603_1608Metric_Pad1.08x0.95mm_HandSolder
C2, C3: 1uF; C_0603_1608Metric_Pad1.08x0.95mm_HandSolder
D1, D2: MP-3030-120H-30-80; LED_MP-3030-120H-30-80; PARTREV Rev 03
J1: Conn_01x04_Pin; PinSocket_1x04_P2.54mm_Vertical
Q1, Q2: BSS138; SOT-23_3L_ONS; PARTREV 30 Jan 2018
R1, R2: 22; R_0603_1608Metric_Pad0.98x0.95mm_HandSolder
R5, R6, R7, R8: 4.7k; R_0603_1608Metric_Pad0.98x0.95mm_HandSolder
U1: AS7341-DLGT; SON8_AS7341-DLGM_AMS; PARTREV V3
U3: MCP1700x-180xxTT; SOT-23

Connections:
+1V8: C1.1, C2.1, Q1.1, Q2.1, U1.1 (VDD), U3.2 (VO)
+3.3V: C3.1, D1.A, D2.A, J1.1, U3.3 (VI)
/LDR: R1.1, R2.1, U1.4 (LDR)
/SCL: R7.2, U1.2 (SCL)
/SCL_3V3: J1.3, R8.1
/SDA: R5.2, U1.8 (SDA)
/SDA_3V3: J1.4, R6.1
GND: C1.2, C2.2, C3.2, J1.2, U1.3 (GND), U1.5 (PGND), U3.1 (GND)
unnamed: D1.C, R1.2
unnamed: D2.C, R2.2
unnamed: Q1.2, R5.1
unnamed: Q1.3, R6.2
unnamed: Q2.2, R7.1
unnamed: Q2.3, R8.2

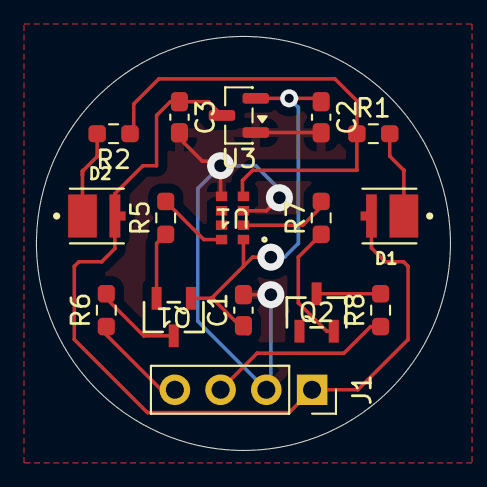
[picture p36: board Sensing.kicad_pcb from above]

Board: 2 copper layers, 23.0 x 23.0 mm, 16 parts (0 on the bottom side), 14 nets.

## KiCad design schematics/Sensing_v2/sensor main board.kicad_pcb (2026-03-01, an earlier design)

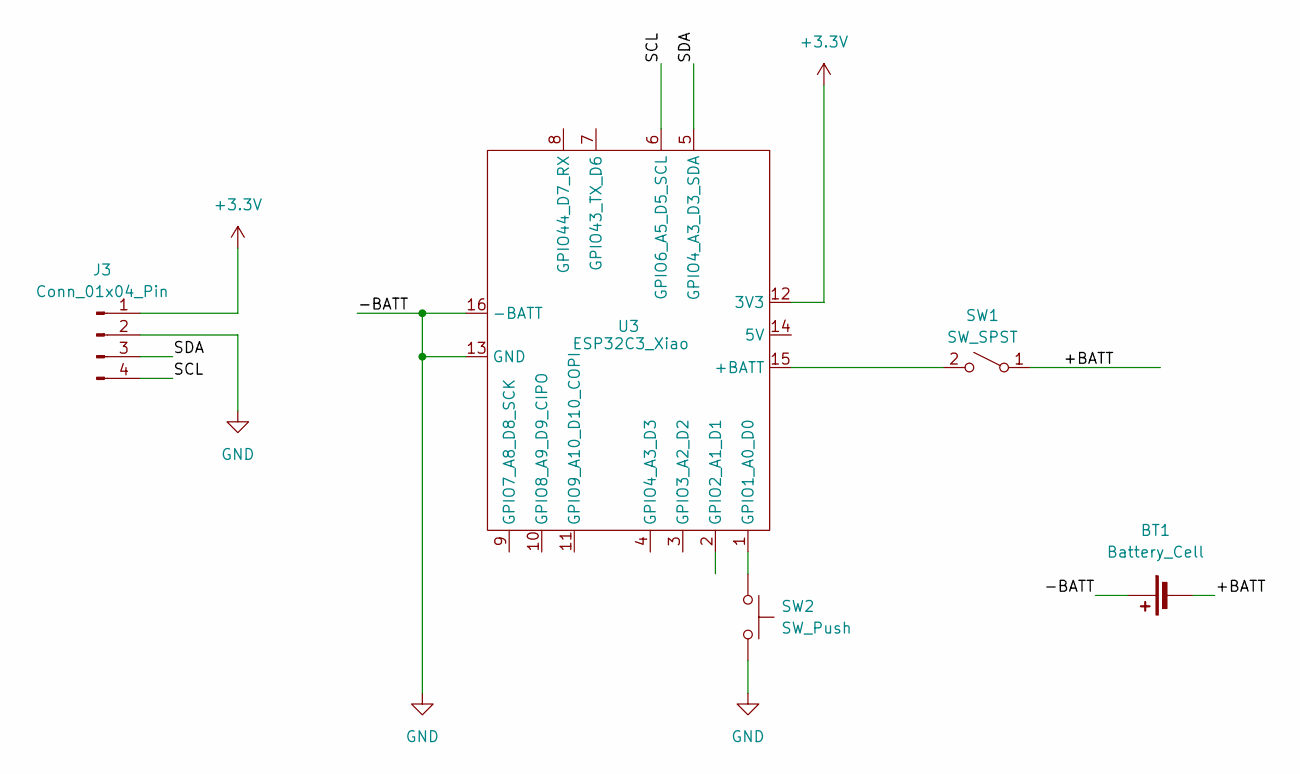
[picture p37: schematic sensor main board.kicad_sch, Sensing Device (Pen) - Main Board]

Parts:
BT1: Battery_Cell; BatteryHolder_Keystone_2466_1xAAA
J3: Conn_01x04_Pin; PinSocket_1x04_P2.54mm_Vertical
SW1: SW_SPST; PinSocket_1x02_P2.54mm_Vertical
SW2: SW_Push; SW_MEC_5GSH9
U3: ESP32C3_Xiao; XIAO_ESP32

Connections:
+3.3V: J3.1, U3.12 (3V3)
/+BATT: BT1.2 (-), SW1.1 (A)
/SCL: J3.4, U3.6 (GPIO6_A5_D5_SCL)
/SDA: J3.3, U3.5 (GPIO4_A3_D3_SDA)
GND: BT1.1 (+), J3.2, SW2.2, U3.13 (GND), U3.16 (-BATT)
unnamed: SW1.2 (B), U3.15 (+BATT)
unnamed: SW2.1, U3.1 (GPIO1_A0_D0)

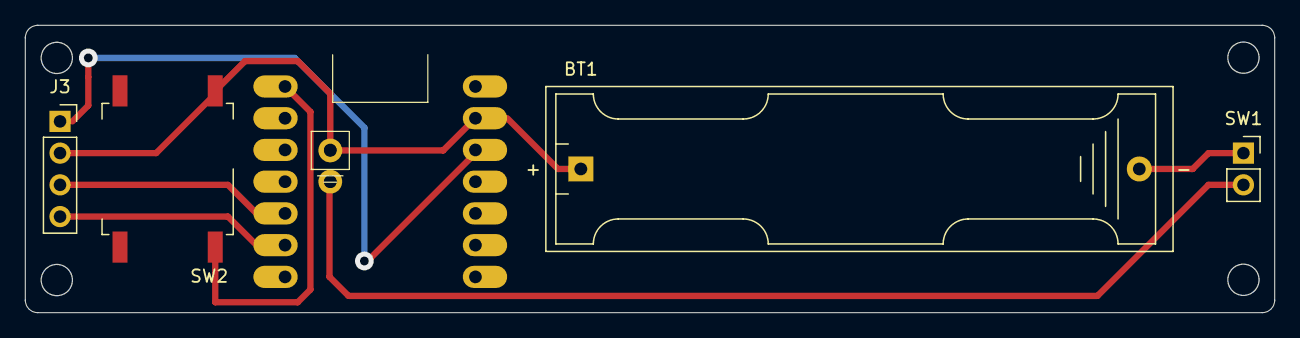
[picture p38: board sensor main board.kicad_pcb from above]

Board: 2 copper layers, 100.0 x 23.0 mm, 5 parts (0 on the bottom side), 7 nets.

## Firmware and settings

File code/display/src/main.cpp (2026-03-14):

#include <Arduino.h>
#include <Wire.h>
#include <WiFi.h>
#include <esp_now.h>
#include <Adafruit_GFX.h>
#include <Adafruit_SSD1306.h>
#include <Adafruit_NeoPixel.h>
#include "pantone_colors.h"

#define PIN_NEO D9

const int M0 = 2;  
const int M1 = 4;  
const int M2 = 1;  
const int M3 = 3;  

Adafruit_SSD1306 oled(128, 64, &Wire, -1);
Adafruit_NeoPixel pixels(2, PIN_NEO, NEO_GRB + NEO_KHZ800);

const int stepSeq[4][4] = {
  {1, 0, 1, 0},
  {0, 1, 1, 0},
  {0, 1, 0, 1},
  {1, 0, 0, 1}
};

int currentStep = 0;
int targetStep = 0;
unsigned long lastMotorTick = 0;
const int motorSpeedDelay = 3; 

const int POS_LOW  = 167; 
const int POS_HIGH = 433; 

// --- ESP-NOW Data Structure ---
typedef struct struct_message {
    uint16_t r;
    uint16_t g;
    uint16_t b;
    uint16_t c;
} struct_message;

struct_message incomingData;
volatile bool newDataReady = false;

// ESP-NOW Receive Callback
void OnDataRecv(const uint8_t * mac, const uint8_t *incomingDataPtr, int len) {
    memcpy(&incomingData, incomingDataPtr, sizeof(incomingData));
    newDataReady = true; 
}

void updateOLED(uint8_t scannedR, uint8_t scannedG, uint8_t scannedB, float conf, String pantoneName) {
    oled.clearDisplay();
    oled.setTextSize(1);
    oled.setTextColor(WHITE);
    oled.setCursor(0, 0);
    
    oled.print("Scanned RGB: ");
    oled.print(scannedR); oled.print(",");
    oled.print(scannedG); oled.print(",");
    oled.println(scannedB);
    oled.println("");

    oled.print("Confidence:  ");
    oled.print(conf, 1); 
    oled.println("%");
    oled.println(""); 

    oled.print("Match: ");
    oled.println(pantoneName);
    oled.println(""); 

    oled.println("[Ready]");
    
    oled.display();
}

void updateNeoPixels(int statusIndicator, uint8_t resultR, uint8_t resultG, uint8_t resultB) {
    switch(statusIndicator) {
        case 0: pixels.setPixelColor(0, pixels.Color(255, 255, 255)); break; 
        case 1: pixels.setPixelColor(0, pixels.Color(0, 0, 255)); break;     
        case 2: pixels.setPixelColor(0, pixels.Color(255, 0, 0)); break;     
        case 3: pixels.setPixelColor(0, pixels.Color(255, 255, 0)); break;   
        case 4: pixels.setPixelColor(0, pixels.Color(0, 255, 0)); break;     
    }

    pixels.setPixelColor(1, pixels.Color(resultR, resultG, resultB));
    pixels.show();
}

void zeroMotor() {
    Serial.println("Calibrating motor to 0...");
    for (int i = 0; i < 600; i++) {
        currentStep--;
        int stepIndex = (currentStep % 4 + 4) % 4; 
        digitalWrite(M0, stepSeq[stepIndex][0]);
        digitalWrite(M1, stepSeq[stepIndex][1]);
        digitalWrite(M2, stepSeq[stepIndex][2]);
        digitalWrite(M3, stepSeq[stepIndex][3]);
        delay(motorSpeedDelay); 
    }
    digitalWrite(M0, LOW); digitalWrite(M1, LOW); 
    digitalWrite(M2, LOW); digitalWrite(M3, LOW);
    currentStep = 0; 
}

void setMotorConfidence(float confidencePercent) {
    confidencePercent = constrain(confidencePercent, 0.0, 100.0);
    zeroMotor(); 
    targetStep = map(confidencePercent, 0, 100, POS_LOW, POS_HIGH); 
}

void runMotorTick() {
    if (millis() - lastMotorTick >= motorSpeedDelay) { 
        if (currentStep != targetStep) {
            if (currentStep < targetStep) currentStep++;
            else currentStep--;
            int stepIndex = (currentStep % 4 + 4) % 4; 
            digitalWrite(M0, stepSeq[stepIndex][0]);
            digitalWrite(M1, stepSeq[stepIndex][1]);
            digitalWrite(M2, stepSeq[stepIndex][2]);
            digitalWrite(M3, stepSeq[stepIndex][3]);
            lastMotorTick = millis();
        } else {
            digitalWrite(M0, LOW); digitalWrite(M1, LOW); 
            digitalWrite(M2, LOW); digitalWrite(M3, LOW);
        }
    }
}

void performKNNAndOutput(uint8_t scannedR, uint8_t scannedG, uint8_t scannedB) {
    int bestIndex = 0;
    float minDistance = 1000.0; 

    // KNN: compute distance to each Pantone color and find the closest match
    for (int i = 0; i < dbSize; i++) {
        float distance = sqrt(pow(scannedR - pantoneDB[i].r, 2) + 
                              pow(scannedG - pantoneDB[i].g, 2) + 
                              pow(scannedB - pantoneDB[i].b, 2));
        if (distance < minDistance) {
            minDistance = distance;
            bestIndex = i;
        }
    }

    String matchedName = pantoneDB[bestIndex].name;
    float confidence = (1.0 - (minDistance / 441.6)) * 100.0;
    
    int statusLevel;
    if (confidence < 40) statusLevel = 2;      
    else if (confidence < 80) statusLevel = 3; 
    else statusLevel = 4;                      

    Serial.printf("KNN Matched: %s | Conf: %.1f%%\n", matchedName.c_str(), confidence);

    // update outputs
    setMotorConfidence(confidence);
    updateOLED(scannedR, scannedG, scannedB, confidence, matchedName);
    updateNeoPixels(statusLevel, scannedR, scannedG, scannedB);
}

void boostSaturation(uint8_t &r, uint8_t &g, uint8_t &b, float factor) {
    // compute luminance and boost saturation by pushing RGB away from the luminance center
    float luminance = (r + g + b) / 3.0;
    
    r = constrain(luminance + (r - luminance) * factor, 0, 200);
    g = constrain(luminance + (g - luminance) * factor, 0, 200);
    b = constrain(luminance + (b - luminance) * factor, 0, 200);
}

void handleInputTuple(uint16_t rawR, uint16_t rawG, uint16_t rawB, uint16_t rawC) {
    if (rawC == 0) return; 
    // Normalize RGB values to 0-255 range based on rawC, then boost saturation for better KNN performance
    uint8_t normR = constrain((rawR * 255) / rawC, 0, 255);
    uint8_t normG = constrain((rawG * 255) / rawC, 0, 255);
    uint8_t normB = constrain((rawB * 255) / rawC, 0, 255);
    
    boostSaturation(normR, normG, normB, 3.0); 
    
    performKNNAndOutput(normR, normG, normB);
}

void setup() {
    Serial.begin(115200);
    
    pinMode(M0, OUTPUT); pinMode(M1, OUTPUT); 
    pinMode(M2, OUTPUT); pinMode(M3, OUTPUT);

    pixels.begin();
    updateNeoPixels(0, 0, 0, 0); 

    Wire.begin(); 
    if(!oled.begin(SSD1306_SWITCHCAPVCC, 0x3C)) {
        Serial.println(F("SSD1306 allocation failed."));
    } else {
        oled.clearDisplay();
        
    
        oled.setTextSize(1);
        oled.setTextColor(WHITE);
        oled.setCursor(0, 0);
        oled.println("System Booting...");
        oled.println("");
        oled.println("");
        oled.println("");
        oled.println("[Ready]");
        oled.display();
    }
    

    WiFi.mode(WIFI_STA);
    if (esp_now_init() != ESP_OK) {
        Serial.println("Error initializing ESP-NOW");
        return;
    }
    esp_now_register_recv_cb(OnDataRecv);

    delay(1000); 
    updateNeoPixels(1, 0, 0, 0);
    Serial.println("Display System Ready. Listening for ESP-NOW...");
}

void loop() {
    runMotorTick(); 

    if (newDataReady) {
        newDataReady = false;
        Serial.printf("\nReceived RX Packet -> R:%d G:%d B:%d C:%d\n", 
                      incomingData.r, incomingData.g, incomingData.b, incomingData.c);
        
        handleInputTuple(incomingData.r, incomingData.g, incomingData.b, incomingData.c);
    }
}

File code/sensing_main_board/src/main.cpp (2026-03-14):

#include <Arduino.h>
#include <Wire.h>
#include <WiFi.h>
#include <esp_now.h>
#include "Adafruit_TCS34725.h"

#define PIN_BUTTON D0
#define PIN_ILLUM_LED D2

Adafruit_TCS34725 tcs = Adafruit_TCS34725(TCS34725_INTEGRATIONTIME_50MS, TCS34725_GAIN_4X);

bool sensorOnline = false;

uint8_t broadcastAddress[] = {0xFF, 0xFF, 0xFF, 0xFF, 0xFF, 0xFF};
typedef struct struct_message { uint16_t r, g, b, c; } struct_message;
struct_message colorData;
esp_now_peer_info_t peerInfo;

bool checkI2CConnection() {
    Wire.beginTransmission(0x29);
    return (Wire.endTransmission() == 0);
}

void tryInitSensor() {
    Serial.println("Attempting to reconnect to TCS34725...");
    if (tcs.begin()) {
        Serial.println(">> SUCCESS: Sensor Connected!");
        sensorOnline = true;
    } else {
        Serial.println(">> FAILED: Sensor not found. Please check wiring (SDA/SCL).");
        sensorOnline = false;
    }
}

void OnDataSent(const uint8_t *mac_addr, esp_now_send_status_t status) {
    Serial.println(status == ESP_NOW_SEND_SUCCESS ? "ESP-NOW: TX OK" : "ESP-NOW: TX FAIL");
}

void setup() {
    Serial.begin(115200);
    delay(3000); 
    
    pinMode(PIN_BUTTON, INPUT_PULLUP);
    pinMode(PIN_ILLUM_LED, OUTPUT);
    digitalWrite(PIN_ILLUM_LED, LOW);

    Wire.begin();
    Wire.setClock(100000); 

    tryInitSensor();

    WiFi.mode(WIFI_STA);
    if (esp_now_init() == ESP_OK) {
        esp_now_register_send_cb(OnDataSent);
        memcpy(peerInfo.peer_addr, broadcastAddress, 6);
        peerInfo.channel = 0;  
        peerInfo.encrypt = false;
        esp_now_add_peer(&peerInfo);
    }
}

unsigned long lastCheckTime = 0;

void loop() {
    unsigned long now = millis();

    if (now - lastCheckTime > 2000) {
        lastCheckTime = now;
        if (!checkI2CConnection()) {
            if (sensorOnline) {
                Serial.println("\n[!] ALERT: Sensor Disconnected!");
                sensorOnline = false;
            }
            tryInitSensor();
        }
    }

    if (sensorOnline && digitalRead(PIN_BUTTON) == LOW) {
        delay(50); 
        if (digitalRead(PIN_BUTTON) == LOW) {
            Serial.println("\n--- Triggered Scan ---");
            
            digitalWrite(PIN_ILLUM_LED, HIGH);
            delay(100); 

            if (checkI2CConnection()) {
                tcs.getRawData(&colorData.r, &colorData.g, &colorData.b, &colorData.c);
                digitalWrite(PIN_ILLUM_LED, LOW);

                Serial.printf("RAW -> R:%d G:%d B:%d C:%d\n", colorData.r, colorData.g, colorData.b, colorData.c);

                if (colorData.c > 0) {
                    esp_now_send(broadcastAddress, (uint8_t *) &colorData, sizeof(colorData));
                }
            } else {
                Serial.println("[ERROR] Bus failed during scan!");
                digitalWrite(PIN_ILLUM_LED, LOW);
                sensorOnline = false;
            }

            while (digitalRead(PIN_BUTTON) == LOW) delay(10);
            Serial.println("Ready.\n");
        }
    }
}

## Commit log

2026-01-27 Update KiCAD
    [Display.csv, Display.kicad_pcb, Display.kicad_sch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]
2026-02-03 Update for PCB design review
    [Display.csv, Display.kicad_sch, Sensing.csv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]
2026-02-05 Custom PCB Design
    [Sensing.csv, Sensing.kicad_pcb, Sensing.kicad_sch]
2026-02-07 Update Battery Estimate
2026-03-01 Update PCB and Enclosure Designs
    [514 Enclosure Design.f3z, 514 Enclosure Design.step, AS7341-DLGT.step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]
2026-03-02 Update Code and Enclosure Screenshots
    [Display_v2_PCB.step]
2026-03-14 Update code
    [Display_v2-B_Cu.gbr, Display_v2-B_Mask.gbr, Display_v2-B_Paste.gbr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]
